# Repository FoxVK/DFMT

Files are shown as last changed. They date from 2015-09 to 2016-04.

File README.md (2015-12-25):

# DFMT
USB Dual FM tuner radio based on PIC 32MX250F128B (or 32MX220F032B) and two LW/SW/FM receivers with I2S output SI4735-D60.

First version of device will alows you to receive sound from first tuner while second tuner can by used for seeking other stations, reciving RDS, obtaining signal metrics, etc...  Unlike SW and FW, hardware was desinged to be as usiversal as possible, so on pcb is interconnection of both audio outputs with MCU, simplified ISP connector and there are soldering pads for both FM and SW/MW/LW inputs.

#Goal
 Be able to receive FM radio with RDS informations.
 
#State of art:
##Firmware:
* Inicialization of tuners is done.
* USB core is done and working.
* USB sunspend is not implemented. Lower power consupmtion to USB spec. limit is not possible but is planned to make it low as possible.
* USB testmode is not implemented and porbably never be because is useful only for certificaion purposes.
* USB-I2C tunnel is done and tested.
* USB audio is done and tesed. (only a subset of audio 1.0 specification)
* USB VID and PID: Random ones are currently used but there seems to be no porblem to get one from Microchip.
* I2C is done and tested.
* I2S is working but there is a problem with discarding buffers due to USB and I2S clock inaccuracy.

##Software:

### Library libdfmt:
* low level interface: Done and tested exept ping.
* Middle level interface is done and tested.
* High level interface is under construction. Only tune cmd is available right now

### Gui:
* Has a bit slow responses because of wrong design
* Tunig and seek works.
* Seek other stations by second tuner. Works but cold be better.
* RDS. Not implemented yet.

## Hardware:
* Schematic was sucessfully tested on breadborad.
* First PCB is finally assembled and successfuly tested.
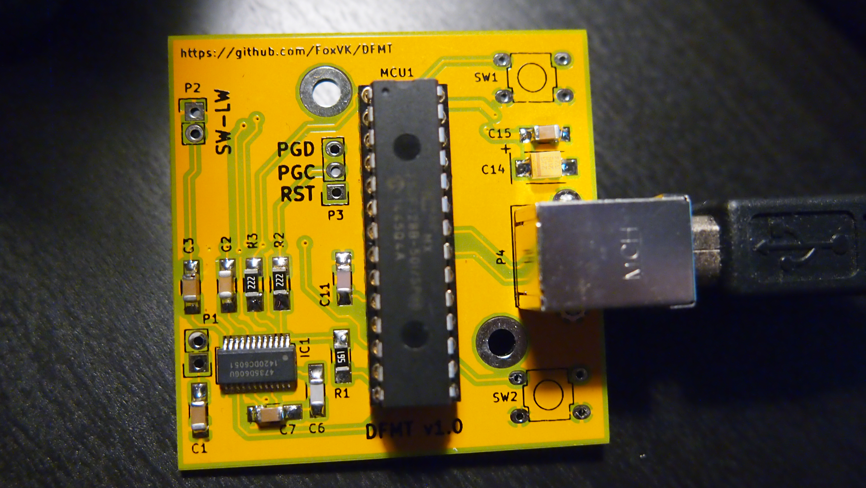
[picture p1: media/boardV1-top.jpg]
PCB

* Issues:
  * Span of holes for buttons is 1mm bigger, but with little bit effort buttons fits.
  * Silkscreen of LE33 and PIC have no orientation mark.
  * Swapped labels PGD and RST.
* Acrylic case could be nice.

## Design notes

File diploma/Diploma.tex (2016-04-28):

% Nejprve uvedeme tridu dokumentu s volbami
\documentclass[czech,master,public,dept460,male,cpdeclaration]{diploma}	% jednostranny dokument

\usepackage[utf8]{inputenc}
\inputencoding{utf8}
\usepackage[czech]{babel}

\usepackage{subfig}		% makra pro "podobrazky" a "podtabulky"
\usepackage{tikz}		% makra pro kresleni

\usepackage{makecell}

\usepackage{pdflscape}

\usepackage{placeins}

\newcommand{\iic}{I\textsuperscript{2}C }
\newcommand{\iis}{I\textsuperscript{2}S }
\newcommand{\eeprom}{E\textsuperscript{2}PROM}

\newcommand{\VID}{0x04D8}
\newcommand{\PID}{0xF32C}

%\widowpenalty10000
%\clubpenalty10000

% Zadame pozadovane vstupy pro generovani titulnich stran.
\ThesisAuthor{Bc. Pavel Kovář}

% U bakalarske praxe neni nutne nazev zadavat
\CzechThesisTitle{Modul USB FM rádia}

% U bakalarske praxe neni nutne anglicky nazev zadavat
\EnglishThesisTitle{USB FM Radio Modul}

\SubmissionDate{29. dubna 2016}

%\PrintPublicationAgreement{true}

\Thanks{Rád bych na tomto místě poděkoval mému vedoucímu panu Ing. Davidu Seidlovi, Ph.D. za cenné rady a trpělivost.}

\CzechAbstract{Tato práce popisuje návrh USB FM přijímače se dvěma tunery. Jeden tuner slouží pro přehrávání zvuku a~druhý pro vyhledávání dalších stanic. Přijímač je v~systému reprezentován jako USB zvuková karta.\\ 
Příjem je realizován dvojicí integrovaných obvodů Si4735-DU. Tyto jsou přes \iis a \iic  spojeny s~MCU PIC32MX250F128B, který přes USB zajišťuje komunikaci s počítačem. V rámci firmware MCU je, po neúspěchu s Microchip harmony frameworkem, napsán vlastní USB stack.\\
Knihovna je napsána v jazyku~C s~využitím knihovny libusb. Poskytuje funkce pro tři úrovně přístupu k~tunerům.\\
Demonstrační aplikace je ve formě grafického uživatelského rozhraní, napsaná  v~C++ s využitím QT frameworku.\\
Vše je funkční pod OS Linux i~Windows.}

\CzechKeywords{FM rádio, USB, RDS, QT, libusb, PIC}

\EnglishAbstract{This work describes design of USB FM radio receiver with two tuners. One tuner is for radio playback, second one seeks new stations. In computer, device acts as sound card.\\
Receiving is done by couple of Si4735-DU integrated circuits, which are connected to MCU via \iic and \iis. MCU forwards data over USB to computer and back. Use of Microchip harmony framework was not successful so in firmware is USB stack written from scratch.\\
Library is written in C with use of libusb library. There are three levels of functions to access tuners.\\
Demo application has graphical user interface and is written in C++ in QT framework.\\
All works under Linux and Windows.}

\EnglishKeywords{FM radio receiver, USB, RDS, QT, libusb, PIC}

% Pridame pouzivane zkratky (pokud nejake pouzivame).
\AddAcronym{AM}{Amlitudová Modulace (Rozhlasové vysílání v pásmu dlouhých vln)}
\AddAcronym{CD}{Compact disc}
\AddAcronym{DAB}{Digital Audio Broadcasting (Digitální pozemní rozhlasové vysílání)}
\AddAcronym{DIP}{Dual Inline Package}
\AddAcronym{FM}{Rozhlasové vysílání v pásmu velmi krátkých vln}
\AddAcronym{HTML}{Hypertext Markup Language}
\AddAcronym{\iic}{Inter-Integrated Circuit}
\AddAcronym{\iis}{Integrated Interchip Sound}
\AddAcronym{LW}{Long Waves (Rozhlasové vysílání v pásmu dlouhých vln)}
\AddAcronym{MCU}{Microcontroller unit}
\AddAcronym{OS}{Operační systém}
\AddAcronym{PCM}{Pulse-code modulation}
\AddAcronym{RDS}{Radio Data System}
\AddAcronym{SPI}{Serial Peripheral Interface}
\AddAcronym{SSOP}{Shrink Small-Outline Package}
\AddAcronym{SW}{Short Waves (Rozhlasové vysílání v pásmu krátkých vln)}
\AddAcronym{USB}{Universal Serial Bus}
\AddAcronym{UTF-16}{Způsob kódování znaků ISO 10646/Unicode}
\AddAcronym{QFN}{Quad Flat No-leads package}

% Zadame cestu a jmeno souboru ci nekolika souboru s digitalizovanou podobou zadani prace
% Pri sazbe se pak hledaji soubory Figures/Zadani1.jpg, Figures/Zadani2.jpg atd.
% Do diplomove prace se postupne vlozi vsechny existujici soubory Figures/ZadaniXXX.jpg
% Pokud toto makro zapoznamkujeme sazi se stranka s upozornenim
\ThesisAssignmentImagePath{figures/zadani}

% Zadame soubor s digitalizovanou podobou prohlaseni
% Pokud toto makro zapoznamkujeme sazi se cisty text prohlaseni
\AuthorDeclarationImageFile{figures/prohlaseni.jpg}

\CooperatingPersonsDeclarationImageFile{figures/souhlas.jpg}

% Zacatek dokumentu
\begin{document}

% Nechame vysazet titulni strany.
\MakeTitlePages

\input{chapters/uvod.tex}

\input{chapters/vyber.tex}
\input{chapters/tuner.tex}
\input{chapters/usb.tex}
\input{chapters/knihovna.tex}

\input{chapters/zaver.tex}

\begin{thebibliography}{99}

\bibitem{usb-complete} AXELSON, Jan. 
\textit{USB complete: the developer's guide.} 4th ed. Madison, WI: Lakeview Research, 2009, xxiii, 504 p. ISBN 1-931448-08-6.

%usb reference
\bibitem{usb-spec} Compaq, Hewlett-Packard, Intel, Lucent, Microsoft, NEC, Philips. 
\textit{Universal Serial Bus Specification: Revision 2.0} [online] 2000-04-27 [2015-12-26]
\url{http://www.usb.org/developers/docs/usb20_docs/usb_20_0702115.zip}

%usb audio 1.0
\bibitem{usb-audio} Gal Ashour, Billy Brackenridge, Oren Tirosh, Altec Lansing, Craig Todd, Remy Zimmermann, Geert Knapen. 
\textit{Universal Serial Bus Device Class Definition for Audio Devices: Release 1.0} [online] 1998-03-18 [2015-12-26]
\url{http://www.usb.org/developers/docs/devclass_docs/audio10.pdf}

%usb audio formats 
\bibitem{usb-audio-formats} Gal Ashour, Billy Brackenridge, Oren Tirosh, Altec Lansing, Craig Todd, Remy Zimmermann, Geert Knapen. 
\textit{Universal Serial Bus Device Class Definition for Audio Data Formats} [online] 1998-03-18 [2016-02-20]
\url{http://www.usb.org/developers/docs/devclass_docs/frmts10.pdf}

%usb lang codes
\bibitem{usb-lang}  USB Implementers’ Forum. 
\textit{Universal Serial Bus Language Identifiers (LANGIDs): Version 1.0} [online] 2000-03-26 [2016-02-09]
\url{http://www.usb.org/developers/docs/USB_LANGIDs.pdf}

\bibitem{tuner-datasheet} Silicon Laboratories,
\textit{Si4730/Si4731/Si4734/Si4735-D60 Broadcast AM/FM/SW/LW Radio Receiver: Rev. 1.2 8/13} [online] 2013-08-08 [2015-12-26] \url{https://www.silabs.com/Support\%20Documents/TechnicalDocs/Si4730-31-34-35-D60.pdf}

\bibitem{tuner-programing} Silicon Laboratories,
\textit{AN332: Si47xx Programming Guide: Rev. 1.0 9/14 } [online] 2014-09-10 [2015-12-26] \url{http://www.silabs.com/Support\%20Documents/TechnicalDocs/AN332.pdf}

%microchip pic
\bibitem{pic} Microchip Technology Inc.
\textit{PIC32MX1XX/2XX Family Data Sheet: Revision H} [online] 2015-07-29 [2015-12-26]
\url{http://ww1.microchip.com/downloads/en/DeviceDoc/60001168H.pdf}

%microchip i2s
%\bibitem{pic-iis} Microchip Technology Inc.
%\textit{PIC32 Family Reference Manual, Sect. 23 Serial Peripheral Interface} [online] 2011-10-11 [2015-12-26]
%\url{http://ww1.microchip.com/downloads/en/DeviceDoc/61106G.pdf}

%microchip i2c
\bibitem{pic-iic} Microchihttp://ww1.microchip.com/downloads/en/DeviceDoc/61116F.pdp Technology Inc.
\textit{PIC32 Family Reference Manual,  Sect 24. Inter-Integrated Circui} [online] 2013-03 [2015-12-26]
\url{http://ww1.microchip.com/downloads/en/DeviceDoc/61116F.pdf}

%microchip dma
%\bibitem{pic-dma} Microchip Technology Inc.
%\textit{PIC32 Family Reference Manual, Sect. 31 DMA Controller} [online] 2013-11-15 [2015-12-26]
%\url{http://ww1.microchip.com/downloads/en/DeviceDoc/60001117H.pdf}

%microchip usb
\bibitem{pic-usb} Microchip Technology Inc.
\textit{PIC32 Family Reference Manual, Sect. 27 USB On-The-Go} [online] 2011-04-13 [2015-12-26]
\url{http://ww1.microchip.com/downloads/en/DeviceDoc/61126F.pdf}

%microchip errata
\bibitem{pic-errata} Microchip Technology Inc.
\textit{PIC32MX1XX/2XX 28/36/44-pin Family Silicon Errata and Data Sheet Clarification} [online] 2015-07-29 [2015-12-26]
\url{http://ww1.microchip.com/downloads/en/DeviceDoc/80000531G.pdf}

%microchip harmony reference
\bibitem{harmony} Microchip Technology Inc.
\textit{MPLAB Harmony USB Libraries Help} [online] 2012-11-15 [2015-12-26]
\url{http://ww1.microchip.com/downloads/en/DeviceDoc/MPLAB\%20Harmony\%20USB\%20Libraries\%20\%28v1.06.02\%29.pdf}

\bibitem{tas}
\textit{TAS1020B USB Streaming Controller} [online] 2011-05 [2015-12-29]
\url{http://www.ti.com/lit/ds/symlink/tas1020b.pdf} 

\bibitem{le} STMicroelectronics
\textit{Very low-dropout voltage regulator with inhibit function} [online] 03-2014 [2016-01-09]
\url{http://www.st.com/st-web-ui/static/active/en/resource/technical/document/datasheet/CD00000545.pdf}

\bibitem{usb-vid} USB.org
\textit{Getting a Vendor ID} [online] [2016-01-16]
\url{http://www.usb.org/developers/vendor/}

\bibitem{iis} Philips Semiconductors
\textit{\iis bus specification} [online] 1996-06-05 [2016-02-27]
\url{http://www.st.com/st-web-ui/static/active/en/resource/technical/document/datasheet/CD00000545.pdf}

\bibitem{rds} EN 50067
\textit{Specification of the radio data system (RDS) for VHF/FM sound broadcasting in the frequency range from 87,5 to 108,0 MHz} CELNEC 04-1998 [2016-04-01]

\bibitem{libwdi} Pete Batard
\textit{libwdi: A Windows Driver Installation library for USB devices} [online] 2016-01-22 [2016-04-25]
\url{https://github.com/pbatard/libwdi#libwdi-a-windows-driver-installation-library-for-usb-devices}

\bibitem{zadig} Pete Batard
\textit{Zadig} [online] 2014-11-21 [2016-04-25]
\url{https://github.com/pbatard/libwdi/wiki/Zadig}

\bibitem{wcid} Pete Batard
\textit{WCID Devices} [online] 2014-11-21 [2016-04-25]
\url{https://github.com/pbatard/libwdi/wiki/WCID-Devices}

\end{thebibliography}

\appendix

\section{Adresářová struktura  přiloženého CD}
\label{sec:ap-cd}

\begin{itemize}
\item \textbf{diploma.pdf}: Tento text.

\item \textbf{firmware}: Projekt pro vývojové prostředí MplabX s firmwarem pro MCU.
	\begin{itemize}
	\item \textbf{dist/default/production/}: Přeložený souboru s firmwarem pro MCU.
	\end{itemize}

\item \textbf{software}: Mutiprojekt s knihovnou a demonstrační aplikací pro vývojové prostředí QT~Creator.
	\begin{itemize}
	\item \textbf{bin}:
		\begin{itemize}
		\item \textbf{win32}: 32-bitová verze knihovny a demonstrační aplikace pro OS Windows.
		\item \textbf{linuxX86\_64}: 64-bitová verze knihovny a demonstrační aplikace pro OS Linux.
		\end{itemize}
	\item \textbf{driver}: Instalátor ovladače pro OS Windows.
	\item \textbf{dfmtgui}: Projekt s demonstrační aplikací.
	\item \textbf{libdfmt}: Projekt s knihovnou.
	\begin{itemize}
		\item \textbf{doc}: Vygenerovaná dokumentace knihovny.
		\end{itemize}
	\end{itemize}
	
\item \textbf{hardware}:
	\begin{itemize}
	\item \textbf{exports}: Schéma ve formátu pdf a soubory pro výrobu desky plošných spojů.
	\item \textbf{kicad}: Projekt se schématem a deskou plošných spojů pro aplikaci KiCad.
	\end{itemize}

\end{itemize}

%\begin{landscape}

\section{Schéma zapojení modulu}
\label{sec:ap-schema}
%Na štorc
%\InsertFigure{figures/dfmt.eps}{50mm}{Schéma zapojení modulu.}{fig:schema}

\begin{center}
 
\end{center}
 
\section{Rozpiska součástek}
\label{sec:ap-bom}
\begin{center}
\begin{tabular}{|l|r|r|r|l|}

\hline
Označení	& Název &	Počet	&	Pouzdro	&	Parametry\\
\hline
\makecell[l]{C1, C7, C9, C12,\\C15, C16}	&	Kondenzátor	&	6	&	1206	&	100 nF 5 \% X7R  50 V\\
\hline
C2, C4	&	Kondenzátor	&	2	&	1206	& 1 nF 5 \% X7R  50 V\\
\hline
C3, C5	&	Kondenzátor	&	2	&	1207	&	470 nF 5 \% X7R  50 V\\
\hline
C6, C8	&	Kondenzátor	&	2	&	1206	&	22 nF 5 \% X7R  50 V\\
\hline
C10, C11	&	Kondenzátor	&	2	&	1206	&	18 pF 5 \% X7R  50 V\\
\hline
C13, C14	&	Kondenzátor	&	2	&	B	&	2,2 $\mu$F 10 \% Tantal 16V \\
\hline
C17	&	Kondenzátor	&	1	&	B	&	10 $\mu$F 10 \% Tantal 16V \\
\hline
IC1, IC2	&	IO	&	2	&	SSOP24	&	SI4735-D60\\
\hline
IC3	&	IO	&	1	&	SO 8	&	LE33-SMT\\
\hline
L1	&	Tlumivka	&	1	&	1210	&	10 $\mu$H 10 \% 180 mA 1,6 $\Omega$\\
\hline
MCU1	&	IO	&	1	&	DIP28	&	PIC32MX220F032B\\
\hline
MCU1	&	Patice	&	1	&	DIP28	&	\\
\hline
P4	&	Konektor	&	1	&		&	USB B zásuvka  MOLEX 670688000 \\
\hline
R1, R4	&	Rezistor	&	2	&	1206	&	560 $\Omega$ 5 \%\\
\hline
R2, R3, R5, R6	&	Rezistor	&	4	&	1206	&	2,2 k$\Omega$ 5 \%\\
\hline
R7, R8, R9	&	Rezistor	&	3	&	1206	&	4,7 k$\Omega$ 5 \%\\
\hline
SW1, SW2	&	Tlačítko	&	2	&		&	TACT 613 N (neosazeno)\\
\hline
Y1	&	Krystal	&	1	&		&	8 MHz 30 ppm HC49SM 18 pF\\
\hline
-	&	Anténa &	1	&	& Vodič	38 cm AWG24\\
\hline

\end{tabular} 
\end{center}
%\end{landscape}

%\clearpage

%\InsertFigure{figures/Graf}{0.7\textwidth}{Nějaký graf}{fig:SampleGraph}

\section{Fotografie osazené desky plošných spojů}
\label{sec:ap-pcb}

\subsection*{Horní strana:}
\begin{center}
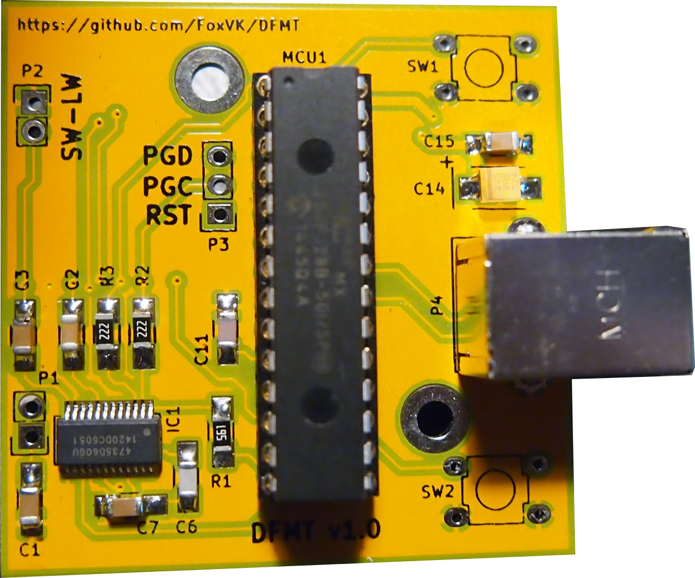
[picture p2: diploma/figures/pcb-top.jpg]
 
\end{center}

\subsection*{Spodní strana:}
\begin{center} 
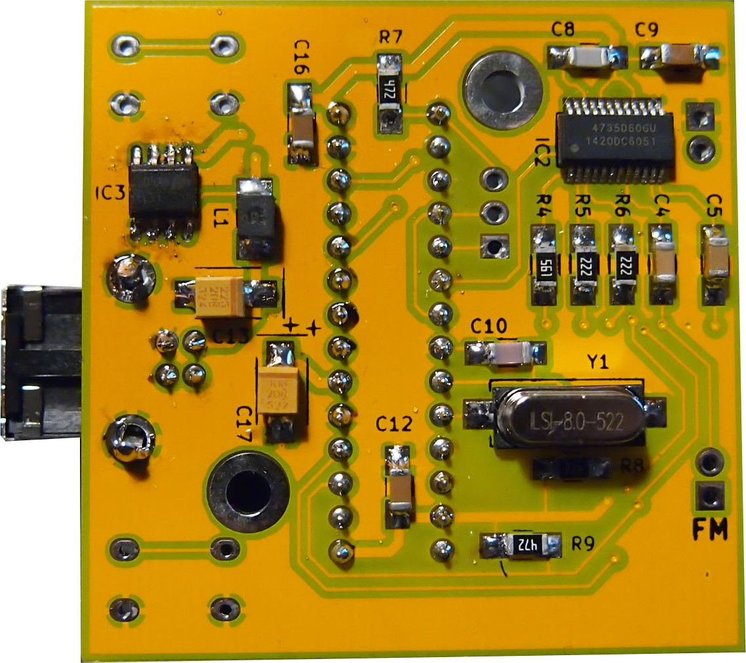
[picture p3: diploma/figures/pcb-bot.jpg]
 
\end{center}

\end{document}

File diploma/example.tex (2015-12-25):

\section{Ukázky sazby}
\label{sec:Typo}

\subsection{Ukázka nadpisů}
Toto je nadpis podsekce, generováno makrem \verb|\subsection|.

\subsubsection{subsection}

\paragraph{paragraph}

\subparagraph{subparagraph}
Ale tak hluboko se asi stejně nikdo nedostane.

\subsection{Sazba definic, vět atd.}
Určitě se bude hodit prostředí pro sazbu definice jako je definice binárního vyhledávacího
stromu, viz definice \ref{def:BinVyhlStrom}.

\begin{remark}
Následující definice a věty nedávají dohromady příliš smysl. Jsou tu jen pro ukázku.
\end{remark}

\begin{definition}
\label{def:BinVyhlStrom}
Binární strom je struktura definovaná nad konečnou množinou uzlů, která:
\begin{itemize}
\item neobsahuje žádný uzel,
\item je složena ze tří disjunktních množin uzlů:
      kořene, binárního stromu zvaného levý podstrom a~binárního stromu tzv.\ pravého podstromu.
\end{itemize}
\end{definition}

Pak by se taky mohla hodit nějaká věta a k ní důkaz.

\begin{theorem}
\label{VetaNeuspechSepar}
Průměrná časová složitost neúspěšného vyhledání  v~hashovací tabulce se  separátním zřetězením je $\Theta(1+\alpha)$, za předpokladu jednoduchého uniformního hashování.
\end{theorem}
\begin{proof}
Za předpokladu jednoduchého uniformního hashování se každý  klíč
$k$ hashuje se stejnou pravděpodobností do libovolného z~$m$ slotů
tabulky. Průměrný čas neúspěšného hledání klíče $k$ je proto
průměrný čas prohledání jednoho z~$m$ seznamů. Průměrná délka
každého takového seznamu je rovna faktoru naplnění $\alpha=n/m$.
Tudíž lze očekávat, že budeme nuceni prozkoumat $\alpha$ prvků.
Z~toho plyne, že celkový čas pro neúspěšné hledání (plus navíc
konstantní čas pro výpočet $h(k)$) je $\Theta(1+\alpha)$.
\end{proof}

\begin{example}
\label{priklad}
Mějme napsat funkci, která spočítá uzly ve stromu. Předpokládejme,
že binární strom je definován způsobem uvedeným v~definici
\ref{def:BinVyhlStrom} na straně \pageref{def:BinVyhlStrom}. Naše úloha se výrazně zjednoduší
uvědomíme-li si její rekurzivní charakter a~předpokládáme, že aktuální uzel je $R$.
\begin{itemize}
\item Je-li $R$ prázdný strom (tj.\ $R=NULL$), pak počet jeho uzlů je pochopitelně nula. Tím máme problém vyřešen.

\item V~opačném případě víme, že ve stromu  určitě jeden uzel existuje ($R$) a~počty uzlů
v~levém a~pravém podstromu se dají určit obdobným způsobem
rekurzivně. To znamená, že počet uzlů ve stromu s~kořenem $R$ je
$1 + \mathrm{pocet\_uzlu}(A) + \mathrm{pocet\_uzlu}(B)$
\end{itemize}

Počty uzlů pro jednotlivé podstromy se předávají jako výsledky
volání funkcí prostřednictvím zásobníku programu, nejsou tudíž
potřeba žádné pomocné proměnné.
\end{example}

\begin{remark}
Program z příkladu \ref{priklad} pochopitelně chybí,
ale můžete se podívat třeba na program uvedený ve výpisu \ref{src:Java}.
\end{remark}

\subsection{Výpisy programů}
Tato diplomová práce má nastaven výchozí jazyk Java, jak je vidět z výpisu~\ref{src:Java}. Výpis kódu \ref{src:Java} zároveň demonstruje možnost přímého vložení zdrojového kódu programu do textu práce. Druhou možností je načtení zdrojového kódu programu z externího souboru, viz výpis \ref{src:JavaExternal}. Pokud potřebujeme změnit programovací jazyk pro konkrétní výpis kódu, můžeme jeho to provést přímo v záhlaví prostředí \verb|lstlisting|. Výpis \ref{src:Pascal} je v jazyku Pascal. Všimněte si zvýraznění klíčových slov. 

\begin{remark}
Pro správnou sazbu je třeba pro odsazování používat tabulátory, nikoliv mezery.
\end{remark}

\begin{lstlisting}[label=src:Java,caption=Program v jazyce Java]
public class MyClass
{
	public int MyMethod(int a, int b)
	{
		while (a != b)
		{
			if (a < b)
				b -= a;
			else
				a -= b;
		}
	}
}
\end{lstlisting}

%\lstinputlisting[label=src:JavaExternal,caption={Program v jazyce Java, načtený z externího souboru}]{MyClass.java}

\begin{lstlisting}[language=Pascal,label=src:Pascal,caption=Program v Pascalu]
procedure X(i : integer; var x : real);
begin
	x := i + 3;
end;
\end{lstlisting}

\subsection{Obrázky a tabulky}
A ještě si můžeme zkusit vysázet obrázek. Obrázek \ref{fig:SampleFigAbs} má určenu absolutní velikost,
zatímco obrázek \ref{fig:SampleFigRel} je určen relativně vůči šířce textu.

\InsertFigure{figures/Obr1}{40mm}{Pokusný obrázek -- absolutní velikost}{fig:SampleFigAbs}

\InsertFigure{figures/Obr1}{0.7\textwidth}{Pokusný obrázek -- relativní velikost}{fig:SampleFigRel}

\InsertSidewaysFigure{figures/Obr1}{0.6\textheight}{Pokusný obrázek -- otočený naležato}{fig:SampleFigSideway}

A ještě zkusíme vysázet několik tabulek, ale jen kvůli seznamu tabulek v úvodu. Tabulka \ref{tab:ExpTable} představuje jednoduchou tabulku, která se svou šířkou pohodlně vejde do šířky textu. Velké tabulky, stejně jako obrázky, můžeme vysázet naležato. Ukázkou velké, komplikované tabulky\footnote{Pokud, ale píšete práci česky, měly by být tabulky také česky -- mě se jen nechtěla předělávat do češtiny.} je tabulka \ref{tab:ExpFilesDetailStats}.
 
\begin{table}
  \centering
  \begin{tabular}{|c|c|c|}
    \hline
    q & $\delta(q, 0)$ & $\delta(q, 1)$ \\
    \hline
    $q_0$ & $q_1$ & $q_0$ \\
    \hline
    $q_1$ & $q_1$ & $q_2$ \\
    \hline
    $q_2$ & $q_1$ & $q_0$ \\
    \hline
  \end{tabular}
  \caption{Pokusná tabulka}
  \label{tab:ExpTable}
\end{table}

\begin{sidewaystable}
\centering
\begin{tabular}{|l|rr|rr|rr|rr|}
\hline
File &
\multicolumn{2}{c|}{bible.txt} &
\multicolumn{2}{c|}{world.txt} &
\multicolumn{2}{c|}{law.txt} &
\multicolumn{2}{c|}{latimes.txt} \\
\hline
Language &
\multicolumn{2}{c|}{English} &
\multicolumn{2}{c|}{English} &
\multicolumn{2}{c|}{Czech} &
\multicolumn{2}{c|}{English} \\
Format &
\multicolumn{2}{c|}{Plain text} &
\multicolumn{2}{c|}{Plain text} &
\multicolumn{2}{c|}{Plain text} &
\multicolumn{2}{c|}{SGML} \\
\hline
Size of file [bytes] & 4047392 &  & 2473400 &  & 64573143 &  & 498360166 & \\
\hline
{\small{}Number of tokens} & 1532262 & 100\% & 684767 & 100\% & 19432898 & 100\% & 161254928 & 100\%\\
{\small{}Number of words} & 766131 & 50\% & 342383 & 50\% & 9716449 & 50\% & 70766067 & 43.885\%\\
{\small{}Number of nonwords} & 766131 & 50\% & 342384 & 50\% & 9716449 & 50\% & 80619289 & 49.995\%\\
{\small{}Number of controls} &  &  &  &  &  &  & 9869572 & 6.12\%\\
\hline
{\small{}Number of unique tokens} & 13791 & 100\% & 23564 & 100\% & 250570 & 100\% & 529482 & 100\%\\
{\small{}Number of unique words} & 13744 & 99.659\% & 23082 & 97.955\% & 246266 & 98.282\% & 524280 & 99.018\%\\
{\small{}Number of unique nonwords} & 47 & 0.341\% & 482 & 2.045\% & 4304 & 1.718\% & 3079 & 0.582\%\\
{\small{}Number of unique controls} &  &  &  &  &  &  & 2123 & 0.401\%\\
\hline
{\small{}Word average frequency} & 55.743 &  & 14.833 &  & 39.455 &  & 134.978 & \\
{\small{}Nonword average frequency} & 16300.66 &  & 710.34 &  & 2257.539 &  & 26183.595 & \\
{\small{}Control average frequency} &  &  &  &  &  &  & 4648.88 & \\
\hline
{\small{}Minimal length of word} & 1 &  & 1 &  & 1 &  & 1 & \\
{\small{}Maximal length of word} & 18 &  & 27 &  & 41 &  & 58 & \\
{\small{}Minimal length of nonword} & 1 &  & 1 &  & 1 &  & 1 & \\
{\small{}Maximal length of nonword} & 4 &  & 56 &  & 700 &  & 253 & \\
{\small{}Minimal length of control} &  &  &  &  &  &  & 3 & \\
{\small{}Maximal length of control} &  &  &  &  &  &  & 132 & \\
\hline
\end{tabular}
\caption{Experimental Files --- Detailed Statistics}
\label{tab:ExpFilesDetailStats}
\end{sidewaystable}

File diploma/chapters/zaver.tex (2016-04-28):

\section{Závěr}
\label{sec:Conclusion}

\InsertFigure{figures/breadborad-landscape.jpg}{123mm}{Modul v kontaktním poli.}{fig:breadborad}

Cílem této práce byl návrh modulu USB FM přijímače, který je v operačním systému reprezentován jako zvuková karta. Přijímač má obsahovat dva tunery, kdy jeden má být používán pro~přehrávání a druhý pro vyhledávání dalších stanic. 

Prvníma dvěma úkoly byl výběr vhodných součástek a ověření funkce zařízení na kontaktním poli. Toto je rozebráno v kapitole \ref{sec:Vyber}. Byly vybrány tunery ve formě integrovaných obvodů SI4735-D60, které budou na sběrnici USB připojeny prostřednictvím mikrokontroléru PIC32MX250F128B. Výslednou konstrukci nejlépe ilustruje obrázek \ref{fig:tuner-block} na straně \pageref{fig:tuner-block}. Do mikrokontroléru byl napsán firmware s vlastním zjednodušeným ovladačem USB. Nad tímto ovladačem běží USB - \iic tunel, pomocí kterého jsou ovládány tunery a rozhraní, které přeposílá digitální zvuk z tunerů do USB. Funkčnost vzniklého zařízení jsem úspěšně ověřil na kontaktním poli (viz.~obrázek \ref{fig:breadborad}). Nad rámec zadání jsme navíc navrhl  desku plošných spojů, na které jsem zařízení úspěšně oživil (fotografie v příloze~\ref{sec:ap-pcb}). Zařízení má v této podobně mnohem kvalitnější příjem. Schéma zapojení je v příloze \ref{sec:ap-schema}. Zároveň je v elektronické verzi spolu s podklady pro výrobu DPS umístěn na~přiloženém CD.

Třetím úkolem bylo napsat knihovnu pro práci s tunerem pod OS Linux a Windows. Knihovna byla napsána v jazyce C s využitím multiplatformní knihovny libusb. Knihovna je rozdělena do~třech vrstev a umožňuje tak snadné rozšíření funkcionality. Knihovna v současné podobně umožňuje přeladění vybraného tuneru na danou frekvenci, vyhledávání stanic a vyčtení parametrů naladěné stanice. Knihovna také byla doplněna o možnost příjmu RDS dat. Ovládání tunerů knihovnou je popsáno v kapitole \ref{sec:tuner}. Samotná knihovna je popsána v kapitole \ref{sec:knihovna}, její rozhraní je podrobně popsáno v dokumentaci vygenerované nástrojem Doxygen, která je umístěna na~přiloženém CD.

Čtvrtým a poslední úkolem bylo napsat uživatelský program, který bude demonstrovat využití knihovny. Napsal jsem aplikaci s grafickým uživatelským rozhraním s využitím multiplatformního frameworku QT5. Tato aplikace umožňuje ladění frekvencí, vyhledávání stanic, zobrazuje parametry signálu naladěné frekvence a její RDS radio text. Zároveň, jak~je~požadováno v~úvodu zadání, průběžně druhým tunerem vyhledává dostupné stanice a zobrazuje je~v~tabulce. Rozhraní nejlépe ilustruje obrázek \ref{fig:gui} na straně \pageref{fig:gui}.

%\subsection{Omezení}

%TODO:
%\begin{itemize}

%\item Nemožnost dostat se v suspendu do 0,5 mA
%\item Test mód neimplementován. Nutný pouze pro získání USB loga.

%suspend a test mod
%\end{itemize}
\FloatBarrier
\subsection{Možnosti dalšího rozšíření}
Hardware a částečně i firmware MCU je připraven pro přenos zvuku i z druhého tuneru. Vhodným doplnění deskriptoru USB konfigurace by bylo možno zařízení přepínat do režimu dvou zvukových karet. Poté by bylo možné nahrávat jinou stanici při současném přehrávání jiné a~nebo využít zařízení pro~streaming několika rozhlasových stanic.  

Na desce plošných spojů jsou připraveny pozice pro dvě tlačítka, která zatím nejsou osazena. Drobnou úpravou firmware by bylo možné využít je k vyhledávání stanic bez potřeby jakéhokoliv dalšího software, popřípadě stisky tlačítek posílat přes USB do aplikace a tam je dále libovolně vyhodnocovat.

Tunery umožňují příjem rozhlasu i na středních a dlouhých vlnách. Toto by vyžadovalo jednak úpravu knihovny, která tunery přepne do režimu pro příjem těchto pásem a také by bylo třeba hardware doplnit o vhodnou anténu spolu s transformátorem viz. katalogový list \cite{tuner-datasheet}.

Uživatelskou aplikaci by bylo vhodné doplnit minimálně o možnost ovládat přehrávání zvuku a popřípadě jeho záznam. Dále je možné doplnit tabulku dostupných frekvencí o informace z~RDS. Taktéž by bylo možné na základě těchto informací automatiky přelaďovat na frekvenci s kvalitnějším příjmem stejné stanice.

\bigskip
\begin{flushright}
Bc. Pavel Kovář
\end{flushright}

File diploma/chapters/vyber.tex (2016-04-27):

\section{Výběr součástek}
\label{sec:Vyber}
Vzhledem k tomu, že není možné se cenou zařízení přiblížit zavedeným výrobcům elektroniky, rozhodl jsme se výběr součástek a~konstrukci modulu přizpůsobit tak, aby bylo možné modul vyrobit v domácích podmínkách.

%mužeš přidat zmínku o snaze mít možnost rozšiřování funkcionality po strance FW a SW
%možná by stáo za to popsat i2s
 
\subsection{Způsob příjmu rozhlasového vyslání}
Jednou možností je řešení přijímačem složeným z diskrétních součástek a nebo pomocí analogových IO. Ovšem toto je příliš komplikované.

Na trhu je řada integrovaných obvodů, které zajišťují samotný příjem vysílání včetně vyhledávání static, měření kvality signálu a přijmu RDS a to s minimem potřebných externích součástek. Tyto IO se typicky ovládají pomocí \iic nebo SPI a zvuk poskytují digitálně přes rozhraní \iis popřípadě analogově. Bohužel drtivá většina těchto IO je dostupná pouze v pouzdru QFN, které se velmi obtížně pájí a je možné je sehnat pouze v minimálním množství 1000 kusů. Výjimkou je SI4735-D60 od výrobce SILICON LABS, který je dostupný v pouzdru SSOP24 a~je možné jej u nás zakoupit i po jednotlivých kusech. IO neumožňuje přijímat DAB, ale umí následující:
\begin{itemize}
\item{Pásma: FM, SW, MW, LW.}
\item{Vzorkovací frekvence až do 48kHz.}
\item{Rozlišení vzorku kanálu až do 24bitů.}
\item{Stereofonní příjem.}
\item{Příjem RDS.}
\end{itemize}
%popis vlastností jako že jsou na 3.3v a taky vypíchnoout že frekvence se dá odvozovat přímo z i2s

\subsection{Volba rozhraní pro spojení modulu a počítače}
Po tomto rozhraní se budou přenášet dva druhy informací a to samotný zvuk a ovládání tunerů.

V současné době je prakticky jediným schůdným řešením použití rozhraní USB díky celé řadě výhod, které nabízí. Zejména jeho širokým rozšířením na téměř všech počítačích, od osobních přes servery až po jednodeskové či průmyslové počítače. Stejně tak je k~dispozici velké množství součástek se zabudovanou podporou tohoto rozhraní. USB dále poskytuje možnost napájení připojených zařízení až do příkonu 2,5 W. Má zabudovanou podporu pro různé druhy přenosů včetně isochronních (garantovaný periodický přenos předem dohodnutého množství dat). Specifikace USB zavádí standardní třídy funkcí v~zařízení. V době psaní tohoto textu sice neexistuje třída pro ovládání tuneru, ale existuje třída popisující zvuková zařízení. Díky tomuto není potřeba vyvíjet vlastní ovladač zvukové karty na straně počítače.
%mužeš to vycpat textem o PCI - PCI-e
\subsubsection{Verze USB specifikací}
V současné době je možné se setkat s USB verze 1.0, 1.1, 2.0 a 3.0. Dobrou zprávou je zpětná kompatibilita všech verzí. tj. zařízení podle specifikace 1.0 by mělo fungovat s jakýmkoliv hostem. Rychlost full speed definuje už první specifikace, její maximální propustnost 12 Mbit je pro věrný přenos dvoukanálového zvuku více než dostatečná. Novější verze nepřinášejí žádnou vlastnost, která by byla pro tento projekt přínosná.

Odlišná situace je v případě specifikací třídy USB audio. Existují vzájemně nekompatibilní verze 1.0 a 2.0. Ani zde mladší verze nepřináší žádný benefit, který bych mohl využít. Navíc doposud nemá nativní podporu ani ve Windows 10. Z tohoto důvodu není použití USB audio 2.0 příliš vhodné.

\subsection{Napojení tuneru na USB}
Požadavky:

\begin{itemize}
\item{Schopnost přenášet dvoukanálový zvuk bez znatelného zkreslení. Zvolil jsem PCM formát o vzorkovací frekvenci 48 kHz a rozlišení 16 bitů na jeden kanál. Pro srovnání audio CD používá 44,1 kHz / 16bitů.}
\item{Alespoň jedno rozhraní \iis schopné přijímat zvuk a fungující v režimu master.}
\item{Podporu pro USB audio. To implikuje nutnost podpory full speed USB a nebo rychlejší. Low speed nepodporuje isochronní přenosy, které jsou nezbytné pro přenos zvuku.}
\item{Rozhraní \iic master pro ovládání tunerů.}
\item{Kompatibilita s 3,3 V logikou tunerů.}
\end{itemize}

\subsubsection{TAS1020b}	
\InsertFigure{figures/tas-block.png}{\textwidth}{Blokové schéma TAS1020b. (Převzato z \cite{tas})}{fig:tas-block}

Jak je patrné z obrázku \ref{fig:tas-block}, jedná se o USB \iis zvukovou kartu a MCU v jednom. Na~rozdíl od~většiny MCU nemá interní paměť programu. Program se načítá při spuštění buď z E\textsuperscript{2}PROM  paměti připojené přes \iic a nebo přes USB ze zařízení, ke kterému je obvod připojen.

Obvod podle specifikace \cite{tas} podporuje všechno potřebné. Full speed USB 1.1 včetně USB audio 1.0, 14 endpointů z toho až dva mohou být isochronní. Dále nabízí až dvě vstupní \iis rozhraní a~jednu \iic sběrnici. Nevýhodou je absence programové paměti, kusová dostupnost obvodu pouze ve formě vzorků a v~mém případě také fakt, že s tímto druhem obvodů nemám žádné zkušenosti.

\subsubsection{PIC16F1454}
PIC16F1454 je osmi bitový MCU od firmy Microchip s podporou full speed USB 2.0. Obvod obsahuje továrně kalibrovaný oscilátor a umí pracovat při napájecím napětí 2,3-5,5V. Díky tomu obvod nepotřebuje prakticky žádné externí součástky. V podstatě k~němu stačí připojit pouze USB kabel.

Výrobce poskytuje k~tomuto MCU knihovnu Microchip Library for aplications, která mimo jiné obsahuje implementaci USB audio 1.0. Navíc jedním ze vzorových projektů u~této knihovny je~i~USB mikrofón, který řeší přenos zvuku do počítače.

Bohužel tento MCU nemá podporu \iis a na jeho softwarovou implementaci je příliš pomalý. 

\subsubsection{PIC32MX250F128}
Tento 32 bitový MCU, taktéž od firmy Microchip, je vybaven všemi potřebnými rozhraními. Full speed USB 2.0, 2x nezávislé \iis, 2x \iic. Pracuje v rozmezí napájecích napětí 2,3-3,6V. V MCU jsou k~dispozici čtyři DMA kanály, které je možné řetězit (po ukončení jednoho kanálu se automaticky spustí druhý). Podobně jako u PIC16F1454 je i k~tomuto čipu k~dispozici framework Harmony \cite{harmony} s podporou pro USB Audio 1.0. Vyrábí se v~různých pouzdrech, dokonce i v DIP, které je možné přímo zapojit do nepájivého pole.\\
Pro modul jsem vybral právě tento MCU. Případně je možné něco málo ušetřit a použít PIC32MX220F032. Liší se pouze menšími velikostmi pamětí, konkrétně 32kB programové paměti místo 128kB a 8kB datové paměti namísto 32kB.

\subsection{Výsledná konstrukce}
\label{subsec:konstrukce}
\InsertFigure{figures/tuner-block.eps}{100mm}{Blokové schéma zapojení.}{fig:tuner-block}

Propojení jednotlivých komponent je naznačeno na obrázku \ref{fig:tuner-block}. Jak je patrné, zahrnul jsem i~propojení tuneru B s MCU přes \iis a také vyvedení anténních AM vstupů tunerů (v obrázku čárkovaně). Aktuálně nejsou využity, ale v budoucnu bude možné zařízení rozšířit o podporu příjmu všech pásem, které tunery podporují a nebo přidat režim, kdy se modul bude chovat jako dvě nezávislé zvukové karty.

Celé zařízení je napájeno z USB přes jediný lineární stabilizátor LE33CD, který snižuje napájecí napětí na~3,3V. Dokáže poskytnout až 100mA a~je odolný proti nadproudu a přehřátí \cite{le}. MCU je zapojen podle doporučení v~katalogovém listu \cite{pic} kapitola 2.1. Stejně tak tunery jsou zapojeny podle doporučení v katalogovém listu \cite{tuner-datasheet} kapitola 2.2.

 Tady bych chtěl zmínit vstup RCLK. Tuner potřebuje v době ladění hodinový signál. V~katalogovém listu je několikrát zmíněno, že tento signál je nutné buď přivést přímo na vstup RCLK a~nebo se získá zapojením 32,768 kHz krystalu. Až v programovací příručce \cite{tuner-programing} v popisu parametru REFCLK\_PRESCALE je možnost odvodit hodinový signál od vstupu hodinového signálu \iis DCLK. Této možnosti jsem samozřejmě využil.
 
Kompletní schéma zapojení je v příloze \ref{sec:ap-schema} a také na přiloženém CD.

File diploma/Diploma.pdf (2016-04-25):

## VŠB – Technická univerzita Ostrava

## Fakulta elektrotechniky a informatiky

## Katedra informatiky

# Modul USB FM rádia

# USB FM Radio Modul

2016 | Bc. Pavel Kovář

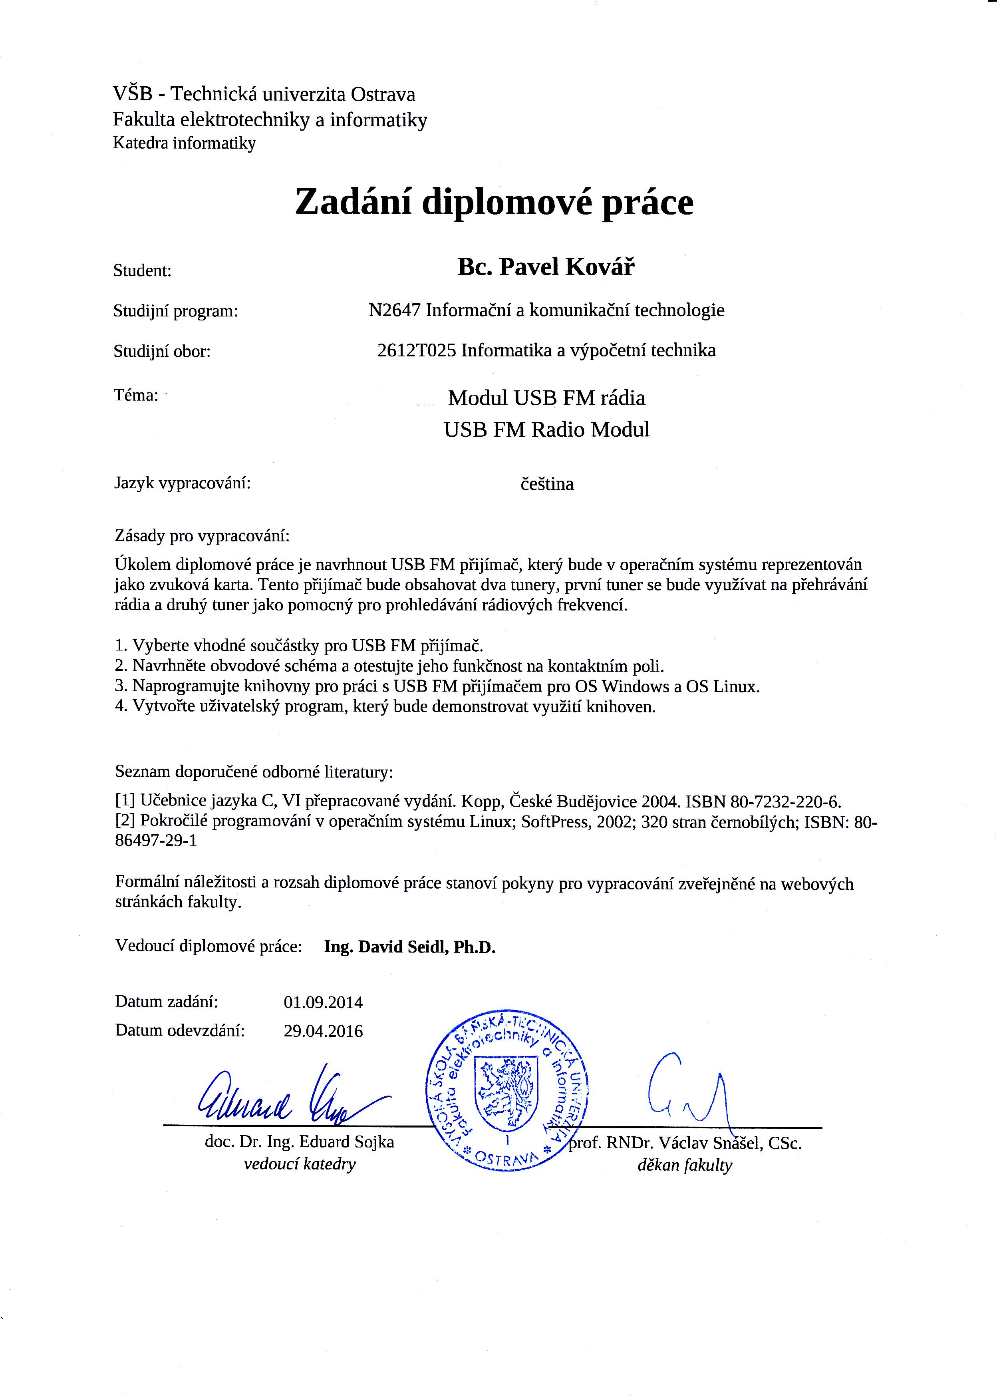
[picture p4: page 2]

Prohlašuji, že jsem tuto diplomovou práci vypracoval samostatně. Uvedl jsem všechny literární prameny a publikace, ze kterých jsem čerpal.

V Ostravě 27. dubna 2016 | |

Souhlasím se zveřejněním této diplomové práce dle požadavků čl. 26, odst. 9 Studijního a zkušebního řádu pro studium v magisterských programech VŠB-TU Ostrava.

V Ostravě 27. dubna 2016 | |

Rád bych na tomto místě poděkoval zejména mému vedoucímu cenné rady a trpělivost.

Abstrakt

Tato práce popisuje návrh USB FM přijímače se dvěma tunery. Jeden tuner slouží pro přehrávání zvuku a druhý pro vyhledávání dalších stanic. přijímač je v systému reprezentován jako USB zvuková karta.
Příjem je realizován dvojicí integrovaných obvodů Si4735-DU. Tyto jsou přes I²S a I²C spojeny

s MCU PIC32MX250F128B, který přes USB zajišťuje komunikaci s počítačem. V rámci firmware MCU je, po neúspěchu s Microchip harmony frameworkem, napsán vlastní USB stack. Knihovna je napsána v jazyku C s využitím knihovny libusb. Poskytuje funkce pro tři úrovně přístupu k tunerům.
Demonstrační aplikace je ve formě grafického uživatelského rozhraní, napsaná v C++ s využitím QT frameworku.
Vše je funkční pod OS Linux i Windows.

Klíčová slova: FM rádio, USB, RDS, QT, libusb, PIC

Abstract

This work describes design of USB FM radio receiver with two tuners. One tuner is for radio playback, second one seeks new stations. In computer, device acts as sound card.
Receiving is done by couple of Si4735-DU integrated circuits, which are connected to MCU via I

2C and I²S . MCU forwards data over USB to computer and back. Use of Microchip harmony

framework was not successful so in firmware is USB stack written from scratch.
Library is written in C with use of libusb library. There are three levels of functions to access tuners.
Demo application has graphical user interface and is written in C++ in QT framework.
All works under Linux and Windows.

Key Words: FM radio receiver, USB, RDS, QT, libusb, PIC

## Obsah

Seznam použitých zkratek a symbolů | 9
Seznam obrázků | 10
Seznam tabulek | 11
1 Úvod | 12
2 Výběr součástek | 13
3 Tuner | 17
4 USB | 26
5 Knihovna a demonstrační aplikace | 48
6 Závěr | 53
Literatura | 54
Přílohy | 55

7

A Schéma zapojení modulu | 56
B Rozpiska součástek | 57

8

## Seznam použitých zkratek a symbolů

AM | – | Amlitudová Modulace (Rozhlasové vysílání v pásmu dlouhých vln)
CD | – | Compact disc
DAB | – | Digital Audio Broadcasting (Digitální pozemní rozhlasové vysílání)
DIP | – | Dual Inline Package
FM | – | Rozhlasové vysílání v pásmu velmi krátkých vln
HTML | – | Hypertext Markup Language
I
2C | – | Inter-Integrated Circuit

I

2S | – | Integrated Interchip Sound
LW | – | Long Waves (Rozhlasové vysílání v pásmu dlouhých vln)
MCU | – | Microcontroller unit
PCM | – | Pulse-code modulation
RDS | – | Radio Data System
SPI | – | Serial Peripheral Interface
SSOP | – | Shrink Small-Outline Package
SW | – | Short Waves (Rozhlasové vysílání v pásmu krátkých vln)
USB | – | Universal Serial Bus
UTF-16 | – | Způsob kódování znaků ISO 10646/Unicode
QFN | – | Quad Flat No-leads package

9

## Seznam obrázků

1 | Blokové schéma TAS1020b. (Převzato z [15]) | | 15
2 | Blokové schéma zapojení | | 16
3 | Časový diagram I²S přenosu. (Převzato z [18]) | | 18
4 | Diagram inicializace tuneru | | 19
5 | Příklad topologie USB sběrnice | | 27
6 | USB koncové body a funkce | | 27
7 | Formát deskriptoru USB bufferu předaného do USB modulu. (Převzato z [12].) . | 41
8 | Formát deskriptoru USB bufferu předaného do aplikace. (Převzato z [12].) . . . . | 41
9 | Zjednodušený diagram stavů USB zařízení | | 44
10 | Instalace ovladače pro Windows | | 51

10

## Seznam tabulek

1 | Popis I²S signálů | | 17
2 | I²C adresy | | 17
3 | Formát příkazu pro tuner | | 18
4 | Formát odpovědi tuneru | | 18
5 | Příkaz spuštění tuneru POWER_UP | | 20
6 | Proměnné použité pro inicializaci tuneru | | 21
7 | Příkaz spuštění tuneru FM_TUNE_FREQ | | 21
8 | Příkaz zjištění stavu ladění FM_TUNE_STATUS | | 21
9 | Odpověď na příkaz zjištění stavu ladění FM_TUNE_STATUS | | 22
10 | Příkaz zjištění stavu ladění FM_TUNE_STATUS | | 22
11 | Proměnná konfigurace příjmu RDS FM_RDS_CONFIG | | 23
12 | Příkaz přečtení přijaté RDS skupiny FM_RDS_STATUS | | 24
13 | Odpověď na příkaz přečtení přijaté RDS skupiny FM_RDS_STATUS | | 24
14 | Druhy USB přenosů | | 26
15 | Deskriptor zařízení | | 30
16 | Obecný formát deskriptorů řetězců | | 30
17 | Deskriptor konfigurace | | 31
18 | Deskriptor řídícího rozhraní zvuku | | 32
19 | Deskriptor řídícího rozhraní zvuku - hlavička | | 33
20 | Deskriptor řídícího rozhraní zvuku - vstupní terminál | | 34
21 | Deskriptor řídícího rozhraní zvuku - výstupní terminál | | 34
22 | Deskriptor rozhraní odesílání zvuku | | 35
23 | Deskriptor rozhraní odesílání zvuku | | 35
24 | Deskriptor formátu zvuku - hlavička | | 35
25 | Deskriptor formátu zvuku | | 36
26 | Deskriptor koncového bodu odesílání zvuku | | 37
27 | Deskriptor koncového bodu odesílání zvuku specifický pro danou třídu | | 38
28 | Deskriptor rozhraní USB - I²C tunelu | | 39
29 | Deskriptor koncových bodů USB - I²C tunelu | | 39
30 | Hlavička USB požadavků | | 43
31 | Formát požadavku USB - I²C tunelu | | 45
32 | Formát odpovědi USB - I²C tunelu | | 46

11

## 1 Úvod

Cílem této diplomové práce je navrhnout USB FM přijímač rádiového vysílání. Přijímač bude v systému reprezentován jako zvuková karta a bude obsahovat dva tunery. Jeden bude sloužit k samotnému příjmu vysílání a druhý k vyhledávání dalších stanic. Dále napsat knihovnu, umožňující ovládání tuneru pod Operačními systémy Linux a Windows. Text této práce je členěn do třech kapitol.
První kapitola se zabývá konstrukcí modulu. Je zde shrnuto a zhodnoceno několik možností jak realizovat jednak samotný příjem rozhlasového vysílání a také několik možností řešení napojení tunerů na USB sběrnici.
Druhá kapitola je věnována popisu vybraného tuneru. Je zde uveden zvolený způsob získání zvukových dat, filozofie ovládání tuneru a popis všech použitých příkazů pro tuneru.
Ve třetí kapitole je rozebráno napojení tunerů na USB sběrnici. Je zde pois USB popis porblémů s harmony , chyby v křemíku použitého MCU, porblémy nesynchronizovaných hodin udesílání zvuku. Popsáno vzniklé USB rozhraní (TODO)
Čtvrtá kapitola se věnuje vzniklé knihovně a demonstračnímu programu. V první části kapi-

toly je popis filozofie a rozvrstvení knihovny včetně popisu funkcí. Doplněno ukázkovým kódem práce. Závěru kapitoly je popsána demonstrační aplikace. (TODO)

12

## 2 Výběr součástek

Vzhledem k tomu, že není možné se cenou zařízení přiblížit zavedeným výrobcům elektroniky, rozhodl jsme se výběr součástek a konstrukci modulu přizpůsobit tak, aby bylo možné modul vyrobit v domácích podmínkách.

### 2.1 Způsob příjmu rozhlasového vyslání

Jednou možností je řešení přijímačem složeným z diskrétních součástek a nebo pomocí analogových IO. Ovšem toto je příliš komplikované.
Na trhu je řada integrovaných obvodů, které zajišťují samotný příjem vysílání včetně vyhledávání static, měření kvality signálu a přijmu RDS a to s minimem potřebných externích součástek. Tyto IO se typicky ovládají pomocí I²C nebo SPI a zvuk poskytují digitálně přes rozhraní I²S popřípadě analogově. Bohužel drtivá většina těchto IO je dostupná pouze v pouzdru

QFN, které se velmi obtížně pájí a je možné je sehnat pouze v minimálním množství 1000 kusů. Výjimkou je SI4735-D60 od výrobce SILICON LABS, který je dostupný v pouzdru SSOP24 a je možné jej u nás zakoupit i po jednotlivých kusech. IO neumožňuje přijímat DAB, ale umí

následující:

- Pásma: FM, SW, MW, LW.
- Vzorkovací frekvence až do 48kHz.
- Rozlišení vzorku kanálu až do 24bitů.
- Stereofonní příjem.
- Příjem RDS.

### 2.2 Volba rozhraní pro spojení modulu a počítače

Po tomto rozhraní se budou přenášet dva druhy informací a to samotný zvuk a ovládání tunerů. V současné době je prakticky jediným schůdným řešením použití rozhraní USB díky celé řadě výhod, které nabízí. Zejména jeho širokým rozšířením na téměř všech počítačích, od osobních přes servery až po jednodeskové či průmyslové počítače. Stejně tak je k dispozici velké množství součástek se zabudovanou podporou tohoto rozhraní. USB dále poskytuje možnost napájení připojených zařízení až do příkonu 2,5 W. Má zabudovanou podporu pro různé druhy přenosů včetně isochronních (garantovaný periodický přenos předem dohodnutého množství dat). Speci-

fikace USB zavádí standardní třídy funkcí v zařízení. V době psaní tohoto textu sice neexistuje třída pro ovládání tuneru, ale existuje třída popisující zvuková zařízení. Díky tomuto není potřeba vyvíjet vlastní ovladač zvukové karty na straně počítače.

13

### 2.2.1 Verze USB specifikací

V současné době je možné se setkat s USB verze 1.0, 1.1, 2.0 a 3.0. Dobrou zprávou je zpětná kompatibilita všech verzí. tj. zařízení podle specifikace 1.0 by mělo fungovat s jakýmkoliv hostem. Rychlost full speed definuje už první specifikace, její maximální propustnost 12 Mbit je pro věrný přenos dvoukanálového zvuku více než dostatečná. Novější verze nepřinášejí žádnou vlastnost, která by byla pro tento projekt přínosná.
Odlišná situace je v případě specifikací třídy USB audio. Existují vzájemně nekompatibilní verze 1.0 a 2.0. Ani zde mladší verze nepřináší žádný benefit, který bych mohl využít. Navíc doposud nemá nativní podporu ani ve Windows 10. Z tohoto důvodu není použití USB audio 2.0 příliš vhodné.

### 2.3 Napojení tuneru na USB

Požadavky:

- Schopnost přenášet dvoukanálový zvuk bez znatelného zkreslení. Zvolil jsem PCM formát

o vzorkovací frekvenci 48 kHz a rozlišení 16 bitů na jeden kanál. Pro srovnání audio CD používá 44,1 kHz / 16bitů.

- Alespoň jedno rozhraní I²S schopné přijímat zvuk a fungující v režimu master.
- Podporu pro USB audio. To implikuje nutnost podpory full speed USB a nebo rychlejší.

Low speed nepodporuje isochronní přenosy, které jsou nezbytné pro přenos zvuku.

- Rozhraní I²C master pro ovládání tunerů.
- Kompatibilita s 3,3 V logikou tunerů.

### 2.3.1 TAS1020b

Jak je patrné z obrázku 1, jedná se o USB I²S zvukovou kartu a MCU v jednom. Na rozdíl od většiny MCU nemá interní paměť programu. Program se načítá při spuštění buď z E²PROM paměti připojené přes I²C a nebo přes USB ze zařízení, ke kterému je obvod připojen.

Obvod podle specifikace [15] podporuje všechno potřebné. Full speed USB 1.1 včetně USB audio 1.0, 14 endpointů z toho až dva mohou být isochronní. Dále nabízí až dvě vstupní I²S rozhraní a jednu I²C sběrnici. Nevýhodou je absence programové paměti, kusová dostupnost obvodu

pouze ve formě vzorků a v mém případě také fakt, že s tímto druhem obvodů nemám žádné zkušenosti.

### 2.3.2 PIC16F1454

PIC16F1454 je osmi bitový MCU od firmy Microchip s podporou full speed USB 2.0. Obvod obsahuje továrně kalibrovaný oscilátor a umí pracovat při napájecím napětí 2,3-5,5V. Díky tomu

14

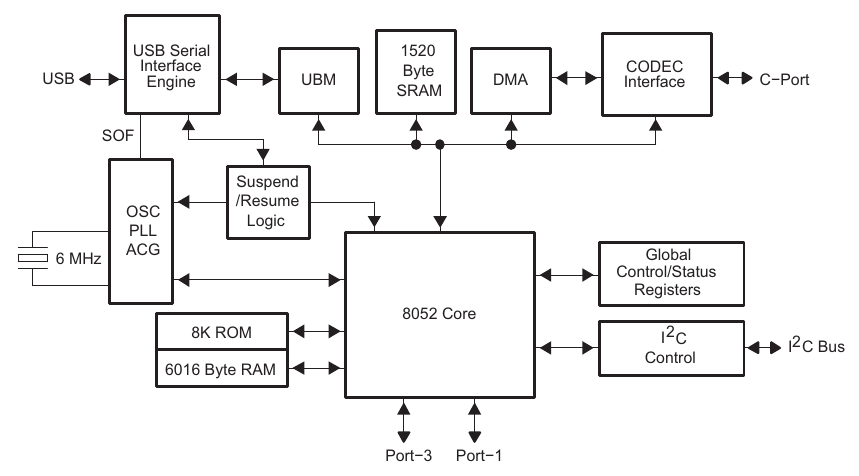
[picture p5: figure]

Obrázek 1: Blokové schéma TAS1020b. (Převzato z [15])

obvod nepotřebuje prakticky žádné externí součástky. V podstatě k němu stačí připojit pouze USB kabel.
Výrobce poskytuje k tomuto MCU knihovnu Microchip Library for aplications, která mimo jiné obsahuje implementaci USB audio 1.0. Navíc jedním ze vzorových projektů u této knihovny je i USB mikrofón, který řeší přenos zvuku do počítače.
Bohužel tento MCU nemá podporu I²S a na jeho softwarovou implementaci je příliš pomalý.

### 2.3.3 PIC32MX250F128

Tento 32 bitový MCU, taktéž od firmy Microchip, je vybaven všemi potřebnými rozhraními. Full speed USB 2.0, 2x nezávislé I²S , 2x I²C . Pracuje v rozmezí napájecích napětí 2,3-3,6V.

V MCU jsou k dispozici čtyři DMA kanály, které je možné řetězit (po ukončení jednoho kanálu se automaticky spustí druhý). Podobně jako u PIC16F1454 je i k tomuto čipu k dispozici framework Harmony [14] s podporou pro USB Audio 1.0. Vyrábí se v různých pouzdrech, dokonce

i v DIP, které je možné přímo zapojit do nepájivého pole.
Pro modul jsem vybral právě tento MCU. Případně je možné něco málo ušetřit a použít PIC32MX220F032. Liší se pouze menšími velikostmi pamětí, konkrétně 32kB programové paměti místo 128kB a 8kB datové paměti namísto 32kB.

15

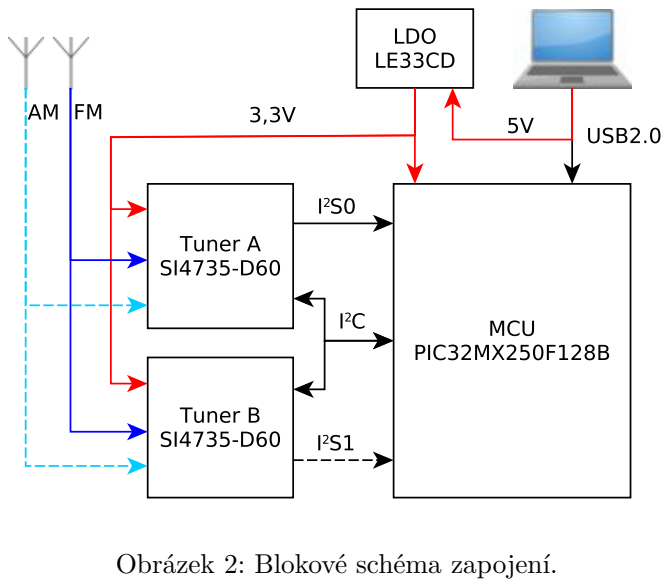
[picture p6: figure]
Obrázek 2: Blokové schéma zapojení.

### 2.4 Výsledná konstrukce

Propojení jednotlivých komponent je naznačeno na obrázku 2. Jak je patrné, zahrnul jsem i propojení tuneru B s MCU přes I²S a také vyvedení anténních AM vstupů tunerů (v obrázku

čárkovaně). Aktuálně nejsou využity, ale v budoucnu bude možné zařízení rozšířit o podporu

příjmu všech pásem, které tunery podporují a nebo přidat režim, kdy se modul bude chovat jako dvě nezávislé zvukové karty.
Celé zařízení je napájeno z USB přes jediný lineární stabilizátor LE33CD, který snižuje napájecí napětí na 3,3V. Dokáže poskytnout až 100mA a je odolný proti nadproudu a přehřátí [16]. MCU je zapojen podle doporučení v katalogovém listu [8] kapitola 2.1. Stejně tak tunery jsou zapojeny podle doporučení v katalogovém listu [6] kapitola 2.2.

Tady bych chtěl zmínit vstup RCLK. Tuner potřebuje v době ladění hodinový signál. V katalogovém listu je několikrát zmíněno, že tento signál je nutné buď přivést přímo na vstup RCLK a nebo se získá zapojením 32,768 kHz krystalu. Až v programovací příručce [7] v popisu parametru REFCLK_PRESCALE je možnost odvodit hodinový signál od vstupu hodinového signálu I²S

DCLK. Této možnosti jsem samozřejmě využil.
Kompletní schéma zapojení je součástí příloh.

16

## 3 Tuner

Jak jsem zmínil v kapitole 2.4 k přijmu rozhlasového vysílání je použit integrovaný obvod SI4735-D60. Zvuk je do MCU přenášen přes rozhraní I²S , samotné ovládání tuneru je realizováno přes sběrnici I²C .

### 3.1 Zvukové rozhraní I²S

MCU | Směr | Tuner | Význam
SDI | ⇒ | DOUT | Datový signál
SCK | ⇒ | DCLK | Hodiny
SS | ⇐ | DFS | Signál určení kanálu

Tabulka 1: Popis I²S signálů.

Rozhraní I²S je v případě jednosměrného přenosu v podstatě rozhraní SPI doplněné o další

datový signál. Význam signálů včetně odpovídajících názvů pinů na MCU a tuneru shrnuje tabulka 1. V případě I²S se nejedná o sběrnici. Vždy komunikují právě dvě zařízení kde jedno je

master a druhé slave. Master vždy vysílá datový signál a signál přepínání kanálů. Datový signál vysílá samozřejmě zřízení, které je zdrojem zvuku. Je možný i obousměrný přenos, potom je nutné použití dvou datových linek.
Tuner umí pracovat pouze v režimu slave, takže hodinový signál a signál přepínání kanálů je generován z MCU. Vzorkování zvuku v tuneru je řízeno jeho vlastním interním oscilátorem. Díky tomuto pravděpodobně občas dojde k zahození některého vzorku pokud MCU čte pomaleji než tuner provádí vzorkování, a nebo dojde k přečtení náhodných dat v opačném případě. Nicméně v praxi jsem s tímto nezaznamenal žádný problém.
Vyjma standardního formátu dat popsaného v I²S specifikace [18] vzniklo ještě několik dalších

formátů. Použil jsem standardní formát, tak jak je zobrazen na obrázku 3.

### 3.2 Ovládací rozhraní I²C

Ovládání tuneru se provádí přes rozhraní I²C . Toto rozhraní je součástí drtivé většiny mikrokontrolérů, není ho třeba blíže popisovat. Tuner se do režimu I²C přepne připojením pinů GPO1

na napájecí napětí a GPO2 k zemi.

SEN | Adresa čtení | Adresa zápisu
0 | 0x23 | 0x22
1 | 0xC7 | 0xC6

Tabulka 2: I²C adresy.

17

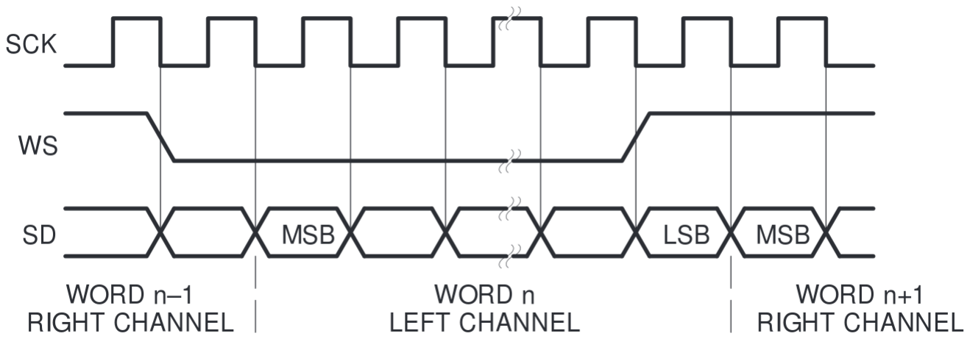
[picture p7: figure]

Obrázek 3: Časový diagram I²S přenosu. (Převzato z [18])

Základní informací nezbytnou pro komunikace s tunerem je I²C adresa. Tuner umožňuje

změnu adresy pomocí změny úrovně na pinu SEN. Adresy jsou v tabulce 2.

### 3.3 Ovládání tuneru

Tuner se ovládá zapisováním příkazů a případným čtením odpovědí. Dále je zde dvojice příkazů pro čtení a zápis proměnných. (properties) tuneru. Kompletní popis všech příkazů a proměnných je v programovací příručce k tuneru [7].

Název pole | Délka
CMD | 1 B | Příkaz.
ARG1 - ARG7 | 0 - 7 B | Případný argument příkazu.

Tabulka 3: Formát příkazu pro tuner.

Název pole | Délka
STATUS | 1 B | Status tuneru.
RESP1 - RESP15 | 0 - 15 B | Případná další data odpovědi.

Tabulka 4: Formát odpovědi tuneru.

Všechny příkazy mají jednotný formát vyobrazený v tabulce 3. Každý příkaz je jednou transakcí zápisu na I²C sběrnici. Případnou odpověď na příkaz je možné získat následnou transakcí čtení z I²C sběrnice. Formát odpovědi je v tabulce 4. Jak je patrné odpověď na každý příkaz

obsahuje vždy minimálně jeden byte se stavem zařízení (STATUS). Význam jednotlivých bitů

v tomto byte je následující:

- Bit 7 CTS - Pokud je v 1 je možné do tuneru odeslat další příkaz.
- Bit 6 ERR - Pokud je v 1 signalizuje chybu provádění příkazu.
- Bity 5 - 3 Rezervováno - Hodnoty těchto bitů nejsou specifikovány.

18

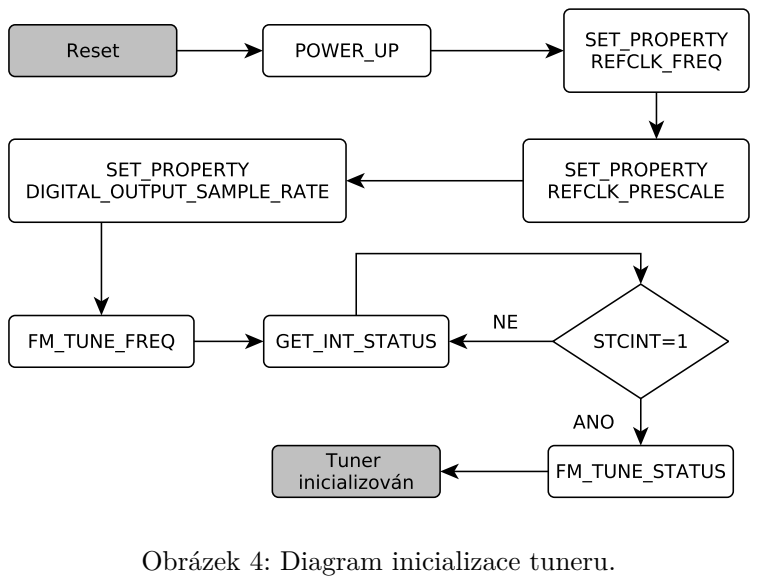
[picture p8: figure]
Obrázek 4: Diagram inicializace tuneru.

- Bit 2 RDSINT - Pokud je v 1 signalizuje vznik přerušení od přijmu RDS.
- Bit 1 ASQINT - Pokud je v 1 signalizuje dokončení měření parametrů přijmu.
- Bit 0 STCINT - Pokud je v 1 signalizuje dokončení ladění nebo vyhledávání stanice.

Bity CTS a ERR se aktualizují vždy. Pro čtení nejnižších třech bitů je potřeba aktualizovat jejich hodnoty příkazem GET_INT_STATUS. Tento příkaz má číslo 0x14 a nemá žádné argumenty. Tuner umožňuje nakonfigurovat signalizaci změny některého z těchto bitů změnou úrovně na výstupu GPO2/INT. Této možnosti jsem se ale rozhodl nevyužít.

Jak jsem zmínil výše, kromě příkazů se parametry tuneru nastavují a nebo čtou pomocí proměnných. jedná se vždy o 16-ti bitové hodnoty, které se identifikují taktéž 16-ti bitovým číslem.
Zápis hodnoty se provádí příkazem SET_PROPERTY (0x12), za kterým následuje jeden

nulový byte, za ním horní a poté dolní byte čísla proměnné. Dále se vyšle horní byte a poté dolní byte vlastní hodnoty.
Čtení se provádí obdobně, příkazem GET_PROPERTY (0x14) za kterým se vyšle nulový

byte následovaný horním a dolním byte čísla zapisované proměnné. Hodnota se získá následným čtením z I²C sběrnice. Horní byte hodnoty je až ve druhém bytu argumentu ARG-2 (viz. tab. 4),

dolní byte v je v ARG-3.

### 3.3.1 Inicializace tuneru

Po spuštění MCU vždy provádí inicializaci obou tunerů. Průběh inicializace shrnuje diagram 4. Z důvodu zkrácení doby spuštění modulu probíhá inicializace formou jednoduchého "multitaskingu". Pokud je jeden tuner zaneprázdněn testuje se stav druhého tuneru a v případě, že

19 není zaneprázdněn dojde k vyslání příkazu, pokud je zaneprázdněn testuje se znova první tuner a tak dále. Ze stejného důvodu je v příkazu FM_TUNE_STATUS nastaven příznak zrychleného

nepřesného ladění.

Bit | 7. | 6. | 5. | 4. | 3. | 2. | 1. | 0.
CMD | 0x01
ARG1 | CTSIEN = 0 | GPO2OEN = 0 | PATCH = 0 | XOSCEN = 0 | FUNC = 0
ARG2 | OPMODE = 0b10110000

Tabulka 5: Příkaz spuštění tuneru POWER_UP.

Inicializace začíná spuštěním tuneru příkazem POWER_UP. Formát příkazu je v tabulce 5. Součástí příkazu jsou tyto parametry:

- CTSIEN - Možnost hardwarové signalizace přerušení v okamžiku kdy je možné odeslat

další příkaz. Hardwarové přerušení nepoužívám.

- GPO2OEN - Nastavení pinu GPO2 jako výstupu.
- PATCH - Umožňuje načtení novějšího firmware do integrovaného obvodu tuneru.
- XOSCEN - Použití krystalu jako zdroje hodinové frekvence. Místo krystalu používám přímo hodinový kmitočet rozhraní I²S .
- FUNC - Použitá hodnota nastaví režim přijmu FM rádia.
- OPMODE - Nastavení výstupu zvuku. Význam hodnoty v tabulce určuje, že bude použit pouze digitální výstup zvuku I²S .

Odpovědí na tento příkaz je pouze jeden byte se statusem tuneru.
Dále je potřeba nastavit dvě proměnné. REFCLK_PRESCALE hodnotu děličky hodinového kmitočtu a do REFCLK_FREQ výslednou frekvenci, která se musí pohybovat v rozsahu 31, 130 − 34, 406Khz. Jak už jsem zmínil jako zdroj hodinové frekvence je použita hodinová frekvence I²S rozhraní. Tato frekvence vyplývá ze součinu počtu kanálů, jejich rozlišení a vzor-

kovací frekvence. 2 · 16 · 48 = 1536kHz. Dělící poměr tedy vychází 1536/32 = 48 při frekvenci

32000kHz.
Zatímco REFCLK_FREQ obsahuje pouze 16-ti bitovou hodnotu frekvence v Hz v RE-FCLK_PRESCALE jsou pro hodnotu dělícího poměru vyhrazeny bity 0-11. Bity 13-15 musí být nulové, bit 12 je nastaven na hodnotu 1, což znamená, že se jako zdroj hodinové frekvence použije I²S .

Poslední proměnná, kterou je potřeba nastavit, je DIGITAL_OUTPUT_SAMPLERATE. Obsahuje hodnotu vzorkovací frekvence. V tomto případě je to hodnota 48000.
Proměnné se nastavují pomocí příkazu SET_PROPERTY popsaného v kapitole 3.3. Výsledné hodnoty a čísla proměnné jsou shrnuty v tabulce 6.

20

Název | Číslo | Hodnota
REFCLK_FREQ | 0x0201 | 0x7D00
REFCLK_PRESCALE | 0x0202 | 0x102A
DIGITAL_OUTPUT_SAMPLE_RATE | 0x0104 | 0xBB80

Tabulka 6: Proměnné použité pro inicializaci tuneru.

Bit | 7. | 6. | 5. | 4. | 3. | 2. | 1. | 0.
CMD | 0x20
ARG1 | 0x00 | | | | | | FREEZE = 0 | FAST = 1
ARG2 | FREQH = 0x24
ARG3 | FREQL = 0x94
ARG4 | ANTCAP = 0x00

Tabulka 7: Příkaz spuštění tuneru FM_TUNE_FREQ.

Poslední částí inicializace tuneru je naladění frekvence 93,7 MHz příkazem FM_TUNE_FREQ. Formát příkazu včetně použitých hodnot je v tabulce 7. Význam parametrů je následující:

- FREEZE - Nastavení způsobí pozvolný přechod zvuku po přeladění.
- FAST - Nastavení způsobí rychlé ale nepřesné přeladění.
- FREQH - Horní byte frekvence v desetinách MHz.
- FREQL - Dolní byte frekvence v desetinách MHz.
- ANTCAP - Nastavení kapacity vstupního kondenzátoru antény. Hodnota 1-191 pF. Hod-

nota 0 znamená automatické nastavení.

Odpovědí na tento příkaz je pouze jeden byte obsahující status tuneru. Dokončení ladění je signalizováno nastavením bitu STCINT ve statusu. K aktualizaci hodnoty tohoto bytu je nutné vždy vyslat příkaz GET_INT_STATUS. Tento příkaz se skládá z jediného byte s číslem příkazu 0x14. Odpovědí na tento příkaz je rovněž jediný byte se statusem tuneru kde jsou aktualizovány hodnoty bitů signalizujících přerušení RDSINT, ASQINT a STCINT.

Bit | 7. | 6. | 5. | 4. | 3. | 2. | 1. | 0.
CMD | 0x22
ARG1 | 0x00 | | | | | | CANCEL = 0 | INTACK = 1

Tabulka 8: Příkaz zjištění stavu ladění FM_TUNE_STATUS.

Ke smazání bitu STCINT je použit příkaz FM_TUNE_STATUS viz. tabulka 8. Kromě smazání tohoto bitu nastavením parametru INTACK je možné nastavením tohoto parametru

21

Bit | 7. | 6. | 5. | 4. | 3. | 2. | 1. | 0.
SATUS | CTS | ERR | X | X | RSQINT | RDSINT | X | STCINT
RESP1 | BLTF | X | X | X | X | X | AFCRL | VALID
RESP2 | READFREQH
RESP3 | READFREQL
RESP4 | RSSI
RESP5 | SNR
RESP6 | MULT

Tabulka 9: Odpověď na příkaz zjištění stavu ladění FM_TUNE_STATUS.

zrušit probíhající ladění nebo vyhledávání stanice. Jak je vidět z tabulky 9, odpověď na příkaz obsahuje kromě statusu tuneru následující informace:

- BLTF - Je nastaven pokud vyhledávání stanice přeteklo přes hodnotu maximální nebo

podteklo hodnotu minimální laditelné frekvence.

- AFCRL - Je nastaven pokud je automatické dolaďování aktivní.
- VALID - Naladěná frekvence byla vyhodnocena jako validní.
- READFREQH - Horní byte naladěné frekvence v desetinách MHz.
- READFREQL - Dolní byte naladěné frekvence v desetinách MHz.
- RSSI - Indikátor síly přijímaného signálu v dBµV.
- SNR - Odstup signálu od šumu v dB.
- MULT - Indikátor míry odrazů v signálu.

### 3.3.2 Vyhledávání stanic

Bit | 7. | 6. | 5. | 4. | 3. | 2. | 1. | 0.
CMD | 0x22
ARG1 | 0x00 | | | | SEEKUP | WRAP | 0x00

Tabulka 10: Příkaz zjištění stavu ladění FM_TUNE_STATUS.

Vyhledávání stanic se provádí pomocí příkazu FM_SEEK_START popsaném v tabulce 10. Příkaz lze parametrizovat pouze pomocí dvou bitů. Nastavením bitu SEEKUP se bude vyhledávat směrem k vyšším frekvencím. Nastavením bitu WRAP bude při dosažení nejvyšší frekvence vyhledávání pokračovat znova od nejnižší frekvence, v případě sestupného vyhledávání se bude

22 po dosažení nejnižší frekvence pokračovat od horní frekvence. Pokud bit WRAP není nastaven, při dosažení nejnižší nebo nejvyšší frekvence dojde k zastavení vyhledávání.
Ukončení vyhledávání je signalizováno nastavením bitu STCINT ve statusu odpovědi tuneru. Detekce ukončení vyhledávání se provádí shodně jako detekce ukončení ladění popsaná v kap. 3.3.1. Naladěnou frekvenci a informace o kvalitě signálu je možné přečíst příkazem FM_TUNE_STATUS, který byl taktéž popsán v kapitole 3.3.1. Tyto informace se vždy aktualizují po naladění, opětovné volání příkazu FM_TUNE_STATUS vrací vždy stejné hodnoty.

### 3.3.3 Čtení RDS z tuneru

RDS je rozšíření pozemního rozhlasového vysílání o souběžné vysílání různých digitálních informací. Z nejznámějších informací je to RT (Radio Text) - přenos až 64 znaků textu, typicky s názvem právě přehrávané skladby a nebo názvem rádiové stanice. Potom AF (Alternative frequency) seznam dalších frekvencí, na kterých je možné stanici naladit, což lze s využitím informace PI (Programme Identification), který stanici jednoznačně identifikuje k automatickému přelaďování na frekvenci s lepším příjmem. Kompletní popis je v [19].

Proud přenášených dat se dělí do třiceti skupin označených 1A, 1B, 2A ... 15A, 15B. Každá skupina má pevně danou velikost 104 bitů a skládá se ze čtyř stejně dlouhých bloků. Chtěl bych upozornit, že v normě [19] jsou tyto bloky označeny čísly 1 až 4, kdežto v programovací příručce tuneru [7] jsou označeny písmeny A až D. Každý blok nese 16 bitů užitečných dat a

10-ti bitové kontrolní slovo. Vyhodnocování chyb v přijatých datech a jejich případnou korekci zajišťuje tuner. Pro příjem je v tuneru k dispozici fronta na 14 skupin.

Bit | 15. | 14. | 13. | 12. | 11. | 10. | 9. | 8.
Horní byte | BLETHA = 2 | | BLETHB = 2 | | BLETHC = 2 | | BLETHD = 2
Bit | 7. | 6. | 5. | 4. | 3. | 2. | 1. | 0.
Dolní byte | 0x00 | | | | | | | RDSEN = 1

Tabulka 11: Proměnná konfigurace příjmu RDS FM_RDS_CONFIG.

Příjem RDS v tuneru je potřeba nejprve nakonfigurovat a povolit. Díky nepoužití hardwarového přerušení, je možné konfiguraci přerušení přeskočit. Konfigurace přijmu RDS se zjednoduší na nastavení jediné proměnné FM_RDS_CONFIG, jejíž formát se nachází v tabulce 11. Nastavením bitu RDSEN této proměnné dojde k povolení přijmu RDS. Pole BLETHA až BLETHD specifikují dovolenou míru chybovosti bloků A až D přijímaných skupin a to takto:

- 0 - Pokud je v bloku jakákoliv chyba celá skupiny bude zahozena.
- 1 - Skupina bude přijata, pokud v bloku došlo k opravě nejvýše dvou bitů.
- 2 - Skupina bude přijata, pokud v bloku došlo k opravě nejvýše pěti bitů.
- 3 - Jakékoliv, i neopravitelné, množství chyb v bloku nezpůsobí zahození skupiny.

23

Bit | 7. | 6. | 5. | 4. | 3. | 2. | 1. | 0.
CMD | 0x24
ARG1 | 0x00 | | | | | STATUSONLY = 0 | 0x00 | INTACK = 1

Tabulka 12: Příkaz přečtení přijaté RDS skupiny FM_RDS_STATUS.

Vyčítání přijatých skupin se potom provádí příkazem FM_RDS_STATUS, uvedeným v tabulce 12. Nastavením bitu STATUSONLY v argumentu tohoto příkazu je možné pouze vyčíst informace o stavu příjmu RDS bez odebrání nejstarší přijaté skupiny z fronty. Nastavením druhého bitu INTACK dojde ke smazání příznaku přerušení RDSINT ve statusu tuneru. Vzhledem k nepoužití přerušení nastavení bitu INTACK nemá význam.

Bit | 7. | 6. | 5. | 4. | 3. | 2. | 1. | 0.
SATUS | CTS | ERR | X | X | RSQINT | RDSINT | X | STCINT
RESP1 | X | X | RDSNEW BLOCKB | RDSSYNC BLOCKA | X | RDSSYNC FOUND | RDSSYNC LOST | RDSRECV
RESP2 | X | X | X | X | X | GRPLOST | X | RDSSYNC
RESP3 | RDSFIFOUSED
RESP4 | BLOCKAH
RESP5 | BLOCKAL
RESP6 | BLOCKBH
RESP7 | BLOCKBL
RESP8 | BLOCKCH
RESP9 | BLOCKCL
RESP10 | BLOCKDH
RESP11 | BLOCKDL
RESP12 | BLEA | | BLEB | | BLEC | | BLED

Tabulka 13: Odpověď na příkaz přečtení přijaté RDS skupiny FM_RDS_STATUS.

Odpověď na tento příkaz v tabulce 13 je podle očekávání poněkud obsáhlejší. První byte obstahuje jako vždy status tuneru. V následujících dvou bytech za statusem jsou bity jejihž LOG 1 má následující význam:

- RDSNEWBLOCKB, RDSNEWBLOCKA - Byl přijat validní blok B nebo A.
- RDSSYNCFOUND - Příjem RDS je synchronizován.
- RDSSYNCLOST - Ztracena synchronizace příjmu RDS, např. z důvodu špatného sig-

nálu.

- RDSRECV - Nastaven pokud je ve frontě počet skupin větší nebo roven hodnotě pro-

měnné FM_RDS_INT_FIFO_COUNT. Tato proměnná byla ponechána ve výchozím nastavení na hodnotě 0, takže tento bit bude nastaven vždy.

- GRPLOST - Přetečení fronty přijatých skupin.

24

- RDSSYNC - Příjem RDS je synchronizován. (Aktuální stav.)

V bytu RDSFIFOUSED je počet skupin ve frontě. Pokud je tato hodnota větší než nula, v následujících osmi bytech se nachází data nejstarší přijaté skupiny. V posledním byte odpovědi jsou informace o chybovosti přijmu jednotlivých bloků skupiny BLEA až BLED. Význam hodnot

chybovosti je tento:

- 0 - Blok přijat bez chyby.
- 1 - V bloku došlo k opravě jednoho až dvou bitů.
- 2 - V bloku došlo k opravě tří až pěti bitů.
- 3 - Blok nebylo možné opravit. Neobsahuje platná data.

Aby nedoházelo k přetečení fronty přijatých skupin, je potřeba frontu vyčítat v dostatečně

krátkých intervalech. Zde je možné využít z pevné délky skupiny 104 b a rychlosti přenosu 1187,5 kHz. Přenos skupiny tedy trvá 87,5 ms. K naplnění 14-ti prvkové fronty tedy dojde nejdříve za 1,2 s. Pokud bude interval vyčítání vždy kratší, k přetečení fronty nedojde.

25

## 4 USB

Na rozdíl od například populárního rozhraní UART je USB podstatně komplikovanější. Je to určitou daní za jeho univerzálnost. Vzhledem k velkému rozsahu specifikace USB [2] se omezím

pouze na popis částí nezbytných pro implementaci modulu.
S vydáním specifikace USB 2.0 byly předchozí specifikace označeny jako zastaralé a neměly by se používat pro nové konstrukce. Následující text se tedy týká USB 2.0 a rychlosti full-speed.

### 4.1 Stručný úvod do full-speed USB 2.0

### 4.1.1 Topologie

Ačkoliv název rozhraní (Univerzální Sériová Sběrnice) napovídá, že jde o sběrnici, jedná se o

zapojení typu hvězda. Přesněji, jak je vidět z obrázku 5, připojená zařízení a rozbočovače tvoří strom jehož kořenem je hostitel. Tento implementuje tzv. kořenový rozbočovač (root hub), ke

kterému je možné buď přímo připojit jedno zařízení a nebo rozbočovač a do něj dalších až osm zařízení/rozbočovačů. Je možné takto za sebe zřetězit až pět rozbočovačů. Celkově je možné na jeden kořenový rozbočovač připojit až 127 zařízení (včetně rozbočovačů).

Velkou výhodou je, že zařízení je od topologie odstíněno. Vždy se z jeho pohledu komunikuje přímo s hostem. Ve specifikaci je také zohledněn fakt, že zařízení zpravidla nezastává pouze jedinou funkci. To je konec konců případ i tohoto modulu. Obsahuje dvě funkce - zvukovou kartu a I²C tunel pro komunikaci s tunery.

### 4.1.2 Komunikace

| Latence | Vyhrazená šířka pásma | Spolehlivý přenos | Typ dat
Isochroní přenos | Minimální | až 90% | Ne | Proud
Hromadný přenos | Negarantovaná | Ne | Ano | Proud
Přenos přerušení | Minimální | až 90% | Ano | Proud
Řídící přenos | Negarantovaná | až 10% | Ano | Zprávy

Tabulka 14: Druhy USB přenosů.

Aby bylo možné uspokojit nároky na přenos (transfer) dat rozdílné povahy různými funkcemi, zavádí specifikace koncové body (endpoint). Osm výstupních (OUT) pro směr z hostitele do zařízení a osm pro směr opačný (IN). Směr je vždy určován právě z pohledu hostitele. Každému

bodu je možné přiřadit jeden ze čtyř druhů přenosu podle tabulky 14. Výjimkou je vstupní a výstupní koncový bod nula. Tyto vždy slouží pro řídící přenosy a na rozdíl od ostatních bodů je musí podporovat všechna zařízení.
Full-speed USB podporuje čtyři druhy komunikace uvedené v tabulce 14.

26

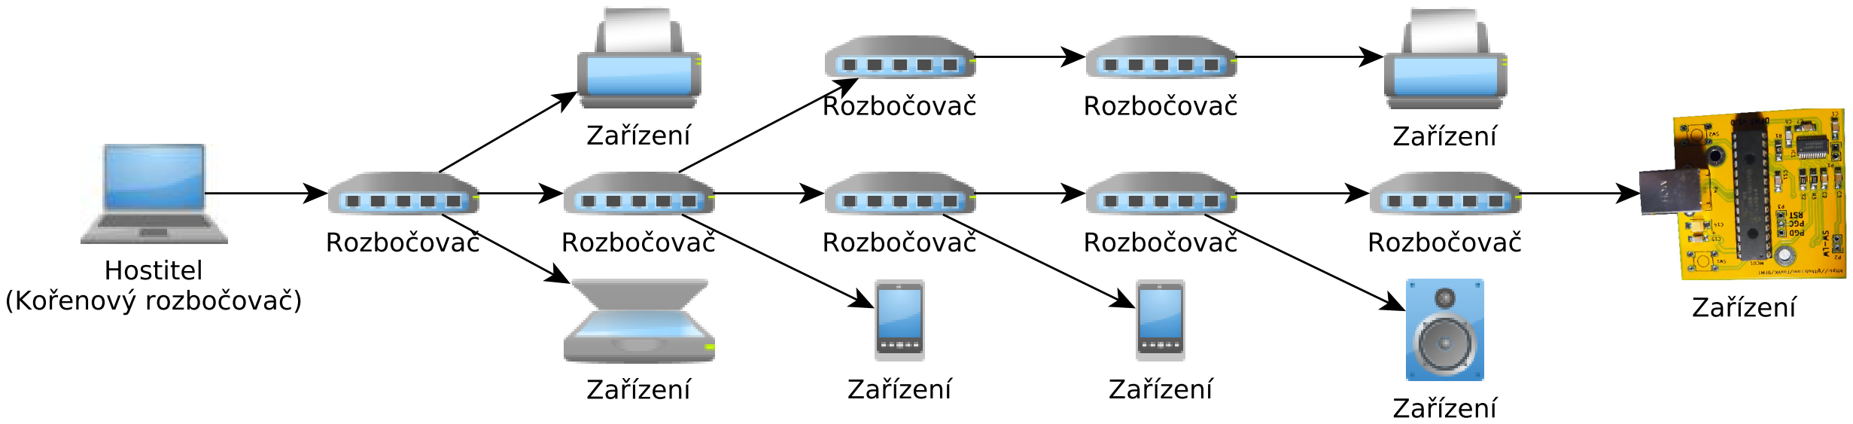
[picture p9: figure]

Obrázek 5: Příklad topologie USB sběrnice.

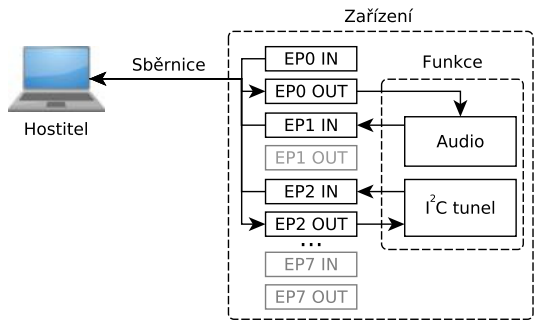
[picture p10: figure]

Obrázek 6: USB koncové body a funkce.

Body nula jsou využívány jednak k inicializaci a správě vlastního zařízení, ale také můžou být využívány zároveň i funkcemi. Například popisovaný modul jej využívá pro ovládání audio funkce. Modul dále využívá vstupní koncový bod 1 pro přenos zvuku do hostitele a potom dvojici koncových bodů 2 v obou směrech pro komunikaci s tunery viz. obrázek 6.
Přenos vždy sestává z alespoň jedné transakce (transaction), která se dále dělí na pakety (packets). Transakce je z pohledu zařízení vždy vyřizována od počátku do konce bez přerušení

jinou transakcí. Je vždy iniciována vysláním token paketu hostitelem, který takto může řídit šířku pásma přidělovanou jednotlivým zařízením na sběrnici. Token pakety mohou být podle druhu transakce následujících třech druhů:

- IN (Vstupní) - Následuje přenos ze zařízení do hostitele.
- OUT (Výstupní) - Následuje přenos z hostitele do zařízení.
- SETUP - Následuje řídící přenos.

Za tímto paketem následuje nula nebo více paketů s daty. Aby bylo možné detekovat výpadek nebo duplikaci některého z paketů jsou specifikovány hned dva typy paketů. A to DATA0 a DATA1. U izochronních transakcí se vždy posílají pakety DATA0. U ostatních transakcí se vyšle nejprve DATA0 a poté se tyto druhy paketů střídají nezávisle na transakcích. Znovu se od DATA0 začne pouze v následujících případech:

27

- Na začátku každé řídící transakce.
- Po následujících žádostech hostitele (bude popsáno dále):

– Přiřazení konfigurace.

– Zrušení zastavení koncového bodu.

– Nastavení rozhraní.

Za datovými pakety následuje potvrzování transakce protistranou. Izochronní přenosy potvrzování nepodporují, tudíž datovými pakety jejich transakce končí. Transkace hromadných přenosů a přenosu přerušení jsou vždy zakončeny jedním potvrzovacím (handshake) paketem. Transkace řídících přenosů mají před potvrzovací paket vložen jeden datový paket nulové délky (zero length packet často zkracovaný ZLP), ale opačného směru než všechny předchozí datové pakety.

Potvrzovací paket vždy vysílá zařízení. Má vždy jeden z následujících typů:

- ACK (Úspěch) - Úspěšné ukončení transakce.
- NAK (Neúspěch) - Typicky poškozená přijímaná data a nebo častěji zařízení nemá při-

pravena data k odeslání.

- STALL (Chyba) - Zařízení takto reaguje na požadavek, který nepodporuje.

Rozdíl mezi NAK a STALL je, že po NAK potvrzení bude hostitel požadavek opakovat (počet opakování není explicitně specifikován), kdežto STALL signalizuje nemožnost vyřízení požadavku

a tudíž jej opakovat nemá smysl.
Formátování a rozpoznávání paketů řeší přímo USB modul v mikrokontroléru, není tedy nutné se jím hlouběji zabývat. Detailní popis je v kapitole 8 USB specifikace [2].

### 4.1.3 Deskriptory

USB specifikace zavádí deskriptory (descriptors). Jedná se o unifikovaný způsob jak může zařízení

informovat hostitele o svých schopnostech a požadavcích. Na základě právě těchto informací může operační systém vybrat pro funkce zařízení odpovídající ovladače, řadič v hostiteli se dozví kolik dat, jak často bude přenášet po jednotlivých koncových bodech a jakou má tomuto přenosu přiřadit prioritu a podobně.
Při vývoji zařízení je základním rozdělením deskriptorů rozdělení podle požadavků hostitele:
- Deskriptor zařízení (Sevice descriptor) - Nejnutnější informace pro správu zařízení

na sběrnici.

- Deskriptory řetězců (String dscriptors) - Pole textových řetěců a informace o dostup-

ných lokalizacích.

- Deskriptory konfigurace (Configuration descriptor) - Struktura deskriptorů s veškerými

dalšími informacemi.

28

Popis všech deskriptorů všech možných funkcí je zcela mimo rozsah tohoto textu. Dále se omezím pouze na deskriptory a jejich hodnoty použité v modulu.

### 4.1.4 Deskriptor zařízení

Název pole | Délka | Hodnota
bLength | 1B | 18 | Délka deskriptoru.
bDescriptorType | 1B | 0x01 | Typ deskriptoru.
bcdUSB | 2B | 0x0200 | Verze USB specifikace implementovaná zařízením. (2.0)
bDeviceClass | 1B | 0x00 | Třída zařízení.0x00 znamená, že třídu specifikuje každé rozhraní zvlášť.
bDeviceSubClass | 1B | 0x00 | Podtřída zařízení. Pokud je bDeviceClass 0x00, musí být i toto pole 0x00.
bDeviceProtocol | 1B | 0x00 | Protokol zařízení. Pokud je bDeviceClass 0x00, musí být i toto pole 0x00.
bMaxPacketSize | 1B | 64 | Největší délka data, kterou je možné odeslat koncovým bodem 0.
idVendor | 2B | 0x04D8 | ID výrobce zařízení.
idProduct | 2B | 0xF32C | ID zařízení.
bcdDevice | 2B | 0x0100 | Verze zařízení 1.0.
iManufacturer | 1B | 1 | Odkaz na řetězec s názvem výrobce.
iProduct | 1B | 2 | Odkaz na řetězec s názvem zařízení.
iSerialNumber | 1B | 0 | Odkaz na řetězec se sériovým číslem zařízení. 0 znamená nespecifikován.
bNumConfigurations | 1B | 1 | Počet konfigurací zařízení.

Tabulka 15: Deskriptor zařízení.

V tabulce 15 je uveden deskriptor zařízení tak, jak je použit v modulu. Myslím, že popis významu polí v tabulce je dostatečný. Za zmínku stojí ID výrobce a zařízení. Jejich účel je stejný jak například MAC adresa síťových zařízení a to jednoznačně identifikovat druh zařízení. Oficiální cesta je požádat o přiřazení ID výrobce USB implementers fórum, což v době psaní toho textu stojí 5000 amerických dolarů [17]. Výrobci programovatelných součástek s podporou

USB, ale naštěstí zpravidla nabízejí možnost zdarma získat ID zařízení z jejich rozsahů. Jednou z podmínek bývá nutnost použít přidělení ID právě na jejich součástce. Pro modul jsem získal ID produktu od firmy Microchip 0xF32C. ID výrobce je 0x04D8.
Pole iManufacturer, iProduct a iSerialNumber nesou indexy na deskriptory textových řetězců. Všechna pole jsou nepovinná. V případě jejich vynechání se použije index s hodnotou
0. Jak napovídají názvy jednotlivých polí, je možné takto přidat popisek výrobce a zařízení ve formě lidsky čitelného textu a sériové číslo daného kusu zařízení, které může využít ovladač v hostiteli například pro načtení posledního nastavení po opětovném připojení zařízení.

29

### 4.1.5 Deskriptory řetězců

Byte | 1. bLength | 2. bDescriptorType | 3. | 4. | 5. | 6. | 2N+1 | 2N+2
Index 0 | 2N+2 | 0x03 | wLANGID[0] | | wLANGID[1] | | wLANGID[N]
Index 1 | 2N+2 | 0x03 | Znak 0 | | Znak 1 | | Znak N

Tabulka 16: Obecný formát deskriptorů řetězců.

Deskriptory řetězců jsou organizovány jako pole indexované od nuly. Každý jeden řetězec začíná hlavičkou deskriptoru, ve které je určen typ deskriptoru a jeho celková délka v bytech. Poté následuje samotný text zakódovaný podle normy unicode, konkrétně UTF-16. Je tedy možné použití i národních znaků.
Jedinou výjimkou je deskriptor s indexem 0. V zařízení je možné mít více sad textů v různých jazycích. Seznam dostupných jazyků (jazykových kódů) je právě v tomto deskriptoru. Seznam těchto kódů popisuje [5]. V modulu jsem se omezil pouze na angličtinu (kód 0x0409). Obecný

formát těchto deskriptorů je naznačen v tabulce 16.

### 4.1.6 Konfigurace zařízení

Konfigurace zařízení je soubor deskriptorů, který popisuje schopnosti zařízení a také jeho nároky na přenos, popřípadě definují sady parametrů z nichž si může hostitel vybrat tu, která mu v daný okamžik nejvíce vyhovuje. Zařízení musí specifikovat minimálně jednu konfiguraci, ale také více. Hostitel potom zařízení jednu přidělí, případně ji může kdykoliv změnit za jinou.
Každá jedna konfigurace začíná deskriptorem konfigurace, za kterým následují deskriptory rozhraní a koncových bodů, do kterých mohou být zanořeny deskriptory další. Tvoří takto stromovou strukturu. V případě mého modulu je možná pouze jediná konfigurace. Její struktura vypadá následovně:
1. Deskriptor řídícího rozhraní zvuku.
(a) Deskriptor řídícího rozhraní zvuku - hlavička.
(b) Deskriptor řídícího rozhraní zvuku - vstupní terminál přijímač rádia.
(c) Deskriptor řídícího rozhraní zvuku - výstupní terminál odesílání zvuku přes USB.
2. Deskriptor rozhraní pro odesílání zvuku - varianta s vypnutým přenosem.
3. Deskriptor rozhraní pro odesílání zvuku - varianta se zapnutým přenosem.
(a) Deskriptor rozhraní pro odesílání zvuku - obecný deskriptor.
(b) Deskriptor rozhraní pro odesílání zvuku - popis formátování dat.
(c) Deskriptor koncového bodu - odesílání zvuku.

30

4. Deskriptor rozhraní specifikovaného výrobcem - I²C tunel.
(a) Deskriptor koncového bodu - odesílání dat hostu.
(b) Deskriptor koncového bodu - příjem dat z hosta.

### 4.1.7 Deskriptor konfigurace

Název pole | Délka | Hodnota
bLength | 1B | 9 | Délka deskriptoru.
bDescriptorType | 1B | 0x02 | Typ deskriptoru.
wTotalLength | 2B | 127 | Celková délka všech deskriptorů konfigurace.
bNumInterfaces | 1B | 3 | Počet rozhraní v konfiguraci.
bConfigurationValue | 1B | 1 | Index této konfigurace.
iConfiguration | 1B | 0 | Odkaz na řetězec s popisem konfigurace.
bmAttributes | 1B | 0b10000000 | Bitová maska s atributy.

Tabulka 17: Deskriptor konfigurace.

Jak je vidět z tabulky 17, tento deskriptor obsahuje informace pro identifikaci konfigurace. A to zejména index iConfiguration. To je hodnota, kterou poté pošle host do zařízení v požadavku o přidělení konfigurace. Dále následuje pole wTotalLength s celkovou délkou konfigurace. Hostitel obdrží všechny případné konfigurace v jednom bloku. Na základě této hodnoty rozliší, kde jednotlivé konfigurace začínají a končí.
Za zmínku také stojí pole bmAttributes. Nejvyšší bit musí být z důvodu kompatibility s USB

1.0 nastaven na 1, nejnižší bity 0-4 jsou rezervovány pro budoucí použití a musí být nastaveny na 0. Bit 6 signalizuje, že zařízení není napájeno z USB sběrnice. Bit 5 signalizuje, že zařízení chce využívat mechanizmus vlastního probuzení a informování hostitele o události. Modul má oba atributy nastaveny na hodnotu 0.

### 4.1.8 Deskriptory konfigurace vztažené k USB audio 1.0

Největší část konfigurace zabírají deskriptory popisující část přenosu zvuku. Je to dáno také tím, že specifikace USB audio [3] nepopisuje pouze přenos audia po USB. Nabízí také prostředky pro

popis topologie vstupů, výstupů, různých efektových jednotek přepínačů, směšovačů a podobně včetně jejich ovládání. Bylo by například možné takto realizovat kompletní ovládání mixážního, kde by přes USB mohlo být realizováno pouze několik vstupů a výstupů a nebo i žádný. pultu Topologie modulu rádia z pohledu této specifikace je nejjednodušší možná. Je zde pouze jeden výstupní terminál přenosu zvuku přes USB, který má jako vstup nastaven vstupní terminál přijímač rádia.

31

Název pole | Délka | Hodnota
bLength | 1B | 9 | Délka deskriptoru.
bDescriptorType | 1B | 0x04 | Typ deskriptoru.
bInterfaceNumber | 1B | 0 | Pořadové číslo rozhraní.
bAlternateSetting | 1B | 0 | Identifikátor alternativní nastavení.
bNumEndpoints | 1B | 0 | Počet koncových bodů v tomto rozhraní.
bInterfaceClass | 1B | 1 | Třída rozhraní. (Audio)
bInterfaceSubClass | 1B | 1 | Podtřída rozhraní. (Control device)
bInterfaceProtocol | 1B | 0 | Vždy 0.
iInterface | 1B | 0 | Index na textový řetězec.

Tabulka 18: Deskriptor řídícího rozhraní zvuku.

Název pole | Délka | Hodnota
bLength | 1B | 9 | Délka deskriptoru.
bDescriptorType | 1B | 0x24 | Typ deskriptoru.
bDescriptorSubType | 1B | 0x01 | Podtyp deskriptoru. (Hlavička)
bcdADC | 2B | 0x0100 | Verze USB Audio specifikace.
wTotalLength | 2B | 30 | Celková délka deskriptorů tohoto rozhraní.
bInCollection | 1B | 1 | Počet rozhraní pro odesílání zvuku.
baInterfaceNr(1) | 1B | 1 | Index rozhraní pro odesílání zvuku.

Tabulka 19: Deskriptor řídícího rozhraní zvuku - hlavička.

32

Název pole | Délka | Hodnota
bLength | 1B | 12 | Délka deskriptoru.
bDescriptorType | 1B | 0x24 | Typ deskriptoru.
bDescriptorSubType | 1B | 0x02 | Podtyp deskriptoru. (Vstupní terminál)
bterminalID | 1B | 1 | Identifikátor terminálu.
wTerminalType | 2B | 0x0710 | Typ terminálu. (Přijímač rádia)
bAssocTerminal | 1B | 0 | Přidružený terminál. (Nejedná se o zvukové propojení)
bNrChannels | 1B | 2 | Počet zvukových kanálů.
wChannelConfig | 2B | 0x0003 | Bitová mapa konfigurace kanálů.
iChannelNames | 1B | 0 | Index na textový řetězec s názvem kanálů.
iTerminal | 1B | 0 | Index na textový řetězec s popisem terminálu.

Tabulka 20: Deskriptor řídícího rozhraní zvuku - vstupní terminál.

Název pole | Délka | Hodnota
bLength | 1B | 9 | Délka deskriptoru.
bDescriptorType | 1B | 0x24 | Typ deskriptoru.
bDescriptorSubType | 1B | 0x03 | Podtyp deskriptoru. (Výstupní terminál)
bterminalID | 1B | 2 | Identifikátor terminálu.
wTerminalType | 2B | 0x0101 | Typ terminálu. (Odesílání přes USB)
bAssocTerminal | 1B | 0 | Přidružený terminál. (Nejedná se o zvukové propojení)
bSourceID | 1B | 1 | Identifikátor připojeného vstupního terminálu.
iTerminal | 1B | 0 | Index na textový řetězec s popisem terminálu.

Tabulka 21: Deskriptor řídícího rozhraní zvuku - výstupní terminál.

Řízení probíhá přes řídící rozhraní zvuku (Audio control interface), které je vždy napojeno

na koncový bod 0. V popisu tohoto rozhraní se skrývá i topologie. Skládá se z deskriptorů v tabulkách 18, 19, 20 a 21.
První deskriptor pouze určuje, že bude následovat popis rozhraní řízení zvuku třídy audio. Následující deskriptor (tabulka 19) tvoří hlavičku třídně specifického popisu rozhraní. Speci-

fikuje jednak použitou verzi USB Audio specifikace a také seznam rozhraní pro odesílání zvuku přes USB. Počet položek v tomto seznamu určuje hodnota pole bInCollection. Poté se na konec deskriptoru pro každé rozhraní přidá jedna položka. V tomto případě je použito pouze jediné rozhraní.
Zbylá dvojice deskriptorů (tabulka 20 a 21) popisuje vlastní topologii. Výstupní terminály

mají vždy pole bSourceID, které se nastaví na hodnotu bTerminalType vstupního terminálu, se kterým je propojen.
Dále následuje sada deskriptorů popisující rozhraní pro odesílání zvuku (audio streaming interface). Stejně jako řídící rozhraní zde se začíná standardním deskriptorem rozhraní, který

nese základní informace o rozhraní.

33

Název pole | Délka | Hodnota
bLength | 1B | 9 | Délka deskriptoru.
bDescriptorType | 1B | 0x04 | Typ deskriptoru.
bInterfaceNumber | 1B | 1 | Pořadové číslo rozhraní.
bAlternateSetting | 1B | 0 | Identifikátor alternativní nastavení.
bNumEndpoints | 1B | 0 | Počet koncových bodů v tomto rozhraní.
bInterfaceClass | 1B | 1 | Třída rozhraní. (Audio)
bInterfaceSubClass | 1B | 2 | Podtřída rozhraní. (Streaming)
bInterfaceProtocol | 1B | 0 | Vždy 0.
iInterface | 1B | 0 | Index na textový řetězec.

Tabulka 22: Deskriptor rozhraní odesílání zvuku.

Název pole | Délka | Hodnota
bLength | 1B | 9 | Délka deskriptoru.
bDescriptorType | 1B | 0x04 | Typ deskriptoru.
bInterfaceNumber | 1B | 1 | Pořadové číslo rozhraní.
bAlternateSetting | 1B | 1 | Identifikátor alternativní nastavení.
bNumEndpoints | 1B | 1 | Počet koncových bodů v tomto rozhraní.
bInterfaceClass | 1B | 1 | Třída rozhraní. (Audio)
bInterfaceSubClass | 1B | 2 | Podtřída rozhraní. (Streaming)
bInterfaceProtocol | 1B | 0 | Vždy 0.
iInterface | 1B | 0 | Index na textový řetězec.

Tabulka 23: Deskriptor rozhraní odesílání zvuku.

V tomto případě jsou použity hned dva deskriptory (tabulka 22 a 23). Liší se pouze ve dvou

polích a to bAlternateSetting a bNumEndpoints. Druhé z těchto polí určuje počet koncových bodů použitých v rozhraní. Díky tomu, že je v prvním deskriptoru tento počet nulový, má hostitel možnost zvolit toto alternativní nastavení vždy, když nemá zájem o zvuková data. K identifikaci tohoto nastavení slouží hodnota v prvním ze zmíněných polí bAlternateSettings.

Název pole | Délka | Hodnota
bLength | 1B | 7 | Délka deskriptoru.
bDescriptorType | 1B | 0x24 | Typ deskriptoru.
bDescriptorSubType | 1B | 1 | Podtyp deskriptoru.
bTerminalLink | 1B | 2 | Index výstupního terminálu.
bDelay | 1B | 1 | Zpoždění v paketech.
wFormatTag | 2B | 1 | Formát přenášených dat. (PCM)

Tabulka 24: Deskriptor formátu zvuku - hlavička.

34

Název pole | Délka | Hodnota
bLength | 1B | 11 | Délka deskriptoru.
bDescriptorType | 1B | 0x24 | Typ deskriptoru.
bDescriptorSubType | 1B | 2 | Podtyp deskriptoru.
bFormatType | 1B | 1 | Typ formátu.
bNrChannels | 1B | 2 | Počet kanálů.
bSubFrameSize | 1B | 2 | Velikost jednoho podrámce v bytech.
bSubFrameResolution | 1B | 16 | Počet platných bitů jednoho podrámce.
bSamFreqType | 1B | 1 | Způsob určení vzorkovací frekvence. (Diskrétní)
tSamFreq(1) | 3B | 48000 | Vzorkovací frekvence v Hz.

Tabulka 25: Deskriptor formátu zvuku.

V tabulce 24 a 25 jsou deskriptory popisující formátování a způsob přenosu zvukových dat. Formátování dat je specifikováno v [4]. Podle tohoto dokumentu se proud zvukových dat dělí do paketů, které se odesílají každou 1 ms. Paket je složen z rámců (frames), které reprezentují úrovně

všech kanálů zachycených v jeden okamžik. Samotné úrovně jednotlivých kanálů se nazývají podrámce (subframes).

Deskriptor třídně specifické hlavičky v tabulce 24 nese kromě polí pro identifikaci sebe sama pouze tři zajímavá pole.
První je bTerminalLink. Identifikuje, ke kterému výstupnímu terminálu se popis formátu vztahuje.
Pole bDelay je hodnota prodlevy mezi zachycením vzorku a jeho odesláním. Veličinou je počet paketů. Hodnota tohoto pole má význam pouze v případe simultánního záznamu zvuku z více zvukových karet a podobně. V případě přijímače rádia na ní nezáleží.
Posledním polem je wFormatTag, které určuje, že hodnoty jednotlivých vzorků budou ve formátu PCM jako čísla se znaménkem. I zde nabízí USB Audio specifikace značnou volnost a kromě formátu PCM je možné přenášet zvuk komprimovaný různými kodeky. Detailnější specifikace je v [4].

Následující deskriptor, vyobrazený v tabulce 25, blíže specifikuje parametry PCM formátu. Toto specifikuje hodnota pole bFormatType.
Jak název napovídá, pole bNrChannels určuje počet kanálů. Pole bSubframeSize obsahuje velikost jednoho podrámce (vzorku) v Bytech. Zároveň pole bSubFrameResolution nese počet

platných bitů v podrámci.
Konec deskriptoru je věnován specifikaci vzorkovacích frekvencí. Pomocí hodnoty v poli bSamFreqType se určí způsob specifikace frekvencí. V případě modulu je použita pouze jediná diskrétní frekvence, která je specifikována v poli tSamFreq(1). Je možné zde specifikovat více

diskrétních frekvencí, ze kterých si poté hostitel vybírá, a nebo specifikovat interval.
V tabulce 26 je deskriptor koncového bodu popisující koncový bod odesílání zvuku (audio streaming endpoint). Prvním zajímavým polem je adresa koncového bodu v poli bEndpointAdd-

35

Název pole | Délka | Hodnota
bLength | 1B | 7 | Délka deskriptoru.
bDescriptorType | 1B | 0x25 | Typ deskriptoru.
bEndpointAddress | 1B | 0x81 | Číslo koncového bodu.
bmAttributes | 1B | 0b00000001 | Bitová mapa s atributy.
wMaxPacketSize | 2B | 384 | Maximální velikost paketu v bytech.
bInterval | 1B | 1 | Interval Odesílání.
bRefresh | 1B | 0 | Frekvence synchronizace. (Nepoužito)
bSynchAddress | 1B | 0 | Adresa synchronizačního koncového bodu. (Nepoužito)

Tabulka 26: Deskriptor koncového bodu odesílání zvuku.

ress. Jako adresa je použito číslo koncového bodu s tím, že v případě vstupního koncového bodu (směr do hostitele) se sedmý (nejvyšší) bit nastaví na 1. U opačného směru tento bit zůstává

nulový.
Pole bmAttributes obsahuje bitovou mapu atributů koncového bodu. Význam bitů 0 a 1 je

následující:

- 00 - Řídící koncový bod.
- 01 - Izochronní koncový bod.
- 10 - Hromadný koncový bod.
- 11 - Koncový bod přerušení.

Zbylé bity popisují způsob synchronizace izochronních koncových bodů, která ale není použita. Jejich popis je v kapitole 5.12.4 USB specifikace [2].

Pole wMaxPacketsize určuje největší možnou velikost paketu. V tomto případě se spočítá z deskriptoru v tabulce 25 jako bNrChannels · bSubF rameSize ·

tSamF req(1)
1000 Vypočtenou hodnotu
je nutné vždy zaokrouhlit nahoru. Například v případě vzorkovací frekvence 44,1 kHz bude ve většině paketů 44 rámců, ale každý desátý jich bude mít 45.
Pole bInterval určuje periodu čtení dat z koncového bodu. Hodnota 1 znamená, že se bude hostitel pokoušet číst data z koncového bodu každou 1 ms. Zbývající dvě pole se vztahují k synchronizaci, která nebyla použita a tudíž jsou nastavena na hodnotu 0.
Posledním deskriptorem popisujícím přenos zvuku je třídně specifický deskriptor koncového bodu v tabulce 27. Za běžnými uvozujícími poli se nachází bitová mapa s atributy bmAttributes. Význam bitů je následující:
- Bit 0 - Koncový bod podporuje žádost o počáteční nastavení vzorkovací frekvence.
- Bit 1 - Koncový bod podporuje dynamickou změnu vzorkovací frekvence za běhu.

36

Název pole | Délka | Hodnota
bLength | 1B | 9 | Délka deskriptoru.
bDescriptorType | 1B | 0x05 | Typ deskriptoru.
bDescriptorSubType | 1B | 1 | Podtyp deskriptoru.
bmAttributes | 1B | 0b00000000 | Bitová mapa s atributy.
bLockDelayUnits | 1B | 0 | Jednotky prodlevy stabilizace synchronizace. (Nepoužito).
wLockDelay | 2B | 0 | Doba prodlevy stabilizace synchronizace. (Nepoužito)

Tabulka 27: Deskriptor koncového bodu odesílání zvuku specifický pro danou třídu.

- Bit 2-6 - Vyhrazeno - musí být nulové.
- Bit 7 - Pokud je nastaveno musí se přenášená data vždy doplnit nulami tak, aby měl každý

paket velikost wMaxPacketSize.

Dvě pole na konci deskriptoru umožňují specifikovat dobu potřebnou pro stabilizaci synchronizace. Synchronizace koncového bodu není použita, takže obě hodnoty jsou nulové.

37

### 4.1.9 Deskriptory konfigurace vztažené k USB I²C tunelu

Název pole | Délka | Hodnota
bLength | 1B | 9 | Délka deskriptoru.
bDescriptorType | 1B | 0x04 | Typ deskriptoru.
bInterfaceNumber | 1B | 2 | Číslo rozhraní.
bAlternateSettngs | 1B | 0 | Identifikátor alternativního nastavení.
bNumEndpoints | 1B | 2 | Počet koncových bodů v tomto rozhraní.
bInterfaceClass | 1B | 255 | Třída rozhraní (Vendor specific).
bInterfaceSubClass | 1B | 0 | Podtřída rozhraní.
bInterfaceProtocol | 1B | 255 | Protokol rozhraní (Vendor specific).
iInterface | 1B | 0 | Index řetězce s popisem rozhraní (Nepoužit).

Tabulka 28: Deskriptor rozhraní USB - I²C tunelu.

Deskriptor ozhraní USB - I²C tunelu v tabulce 28 je podobný jako zvuková rozhraní. Liší se

samozřejmě třídou zařízení, kde třída 255 určuje, že se nejedná o žádné ze standardizovaných rozhraní, ale je definováno výrobcem. Stejný význam má protokol číslo 255.

Název pole | Délka | Hodnota
bLength | 1B | 9 | Délka deskriptoru.
bDescriptorType | 1B | 0x05 | Typ deskriptoru.
bEndpointAddress | 1B | 0x82 / 0x02 | Číslo koncového bodu.
bmAttributes | 1B | 0b00000010 | Bitová mapa s atributy.
wMaxPacketSize | 2B | 32 | Maximální velikost paketu v bytech.
bInterval | 1B | 0 | Interval Odesílání. (Nemá význam)
bRefresh | 1B | 0 | Frekvence synchronizace. (Nemá význam)
bSynchAddress | 1B | 0 | Adresa synchronizačního koncového bodu. (Nemá význam)

Tabulka 29: Deskriptor koncových bodů USB - I²C tunelu.

V tabulce 29 jsou oba deskriptory koncových bodů pro USB I²C tunel. Liší se pouze v adrese.

Pole bmAttributes obsahuje pouze informaci o tom, že se jedná o koncový bod hromadného přenosu dat (bulk endpoint). Poslední tři pole mají v případě tohoto druhu koncového bodu

vždy hodnotu 0.
Maximální velikost paketu wMaxPacketSize může být 8, 16, 32 nebo 64 B (viz. [2] kap. 5.8.3). Vzhledem k velikosti nejdelšího možného příkazu a odpovědi odesílaného přes I²C , jsem zvolil

velikost 32 B.

38

### 4.2 Microchip Harmony framework

Harmony framework obsahuje mimo jiné také ovladače pro USB včetně USB Audio 1.0. Součástí je i vzorový projekt pro USB reproduktor, ze kterého jsem původně vycházel.
Poté co jsem projekt upravil tak, aby zvuková data nepřijímal, ale odesílal, se začal MCU

restartovat. Z fóra firmy Microchip ( http://www.microchip.com/forums/FindPost/827487)

jsem zjistil, že jde o již nahlášený problém chybné inicializace, v důsledku které dochází k dělení nulou a k resetu MCU. Na fóru je také uveřejněno, jak tuto chybu opravit.
Opravením této chyby jsem se dostal k odesílání zvuku. I když modul správně prošel enumerací a konfigurací, do hostitele se přenášelo pouze ticho. Pomocí USB analyzátoru jsem zjistil, že modul od hostitele dostává IN tokeny, ale posílá pouze pakety nulové délky, jako by neměl žádná data k odeslání.
Rozhodl jsem se implementovat ovladač USB Audia jako vendor endpoint (koncový bod specifikovaný výrobcem). Pro potřeby modulu stačí pouze zajistit odesílání zvuku přes izochronní

koncový bod a reagovat na požadavek změny alternativního nastavení funkce povolením nebo zakázáním izochronního koncového bodu. Došel jsem ke zcela totožnému chování modulu jako s původním ovladačem.
Upravil jsem tedy vlastní ovladač tak, aby izochronní koncový bod byl povolen neustále. Po této úpravě se začal přenášet zvuk, ale implementace vendor endpointu je pravděpodobně příliš pomalá, takže přibližně každý druhý paket byl následován paketem nulové délky.

### 4.3 Vlastní implementace USB

Kvůli zmiňovaným problémům s Harmony frameworkem, které se mi nepodařilo vyřešit, jsem se rozhodl napsat ovladač v MCU sám. Ke zprovoznění USB modulu je potřeba, aby MCU podporoval pouze několik požadavků hostitele a implementovat jednoduchý stavový stroj.

### 4.3.1 USB modul v MCU

Dokumentace USB v MCU se nachází v obecném manuálu [12] pro celou řadu těchto 32 bitových MCU. Detaily pro konkrétní typ jsou v manuálu [8]. Pravděpodobně díky existenci Harmony

frameworku je dokumentace relativně stručná.
USB modul v MCU PIC32MX je velmi podobný USB modulu v 8 bitovém MCU PIC16F1454, na kterém jsem se snažil původně modul tuneru postavit.
Prvním překvapením pro mne bylo, že podle USB specifikace nesmí být na sběrnici přivedeno žádné napětí, pokud není sběrnice napájena z hostitele. U zařízení napájených z USB sběrnice toto není třeba řešit. MCU PIC32 má vyhrazený vstup VBUS právě pro snímání napětí na USB sběrnici. I když je ho možné pomocí konfiguračních slov deaktivovat, je nutné jej použít. Pokud na tento vstup není přivedeno napětí, USB modul v MCU nepracuje.
Vlastní konfigurace USB modulu je v případě USB zařízení v celku jednoduchá. Bitem USBPWR v registru U1PWRC se provede spuštění USB modulu.

39

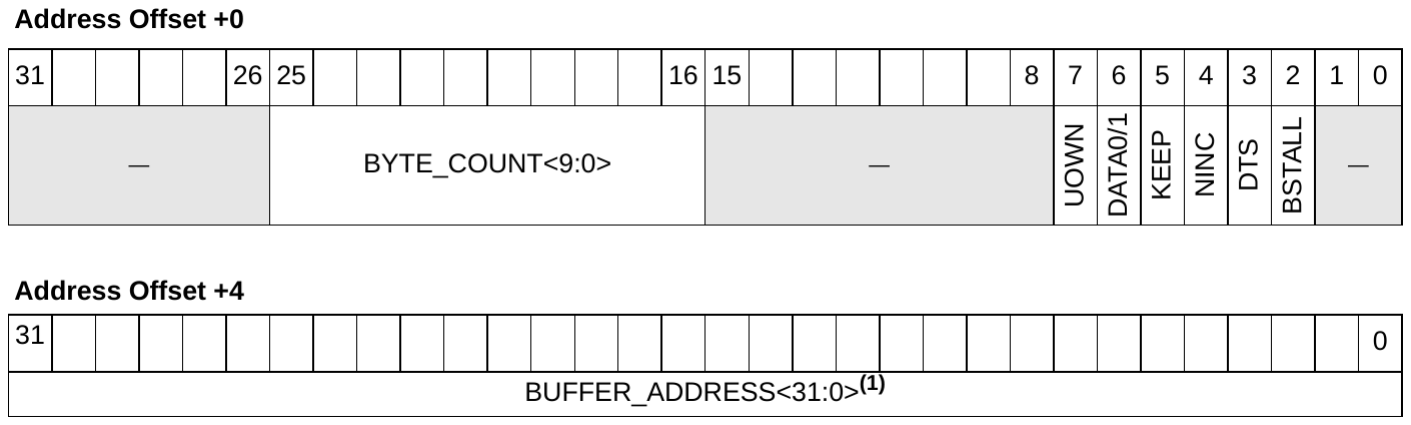
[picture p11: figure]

Obrázek 7: Formát deskriptoru USB bufferu předaného do USB modulu. (Převzato z [12].)

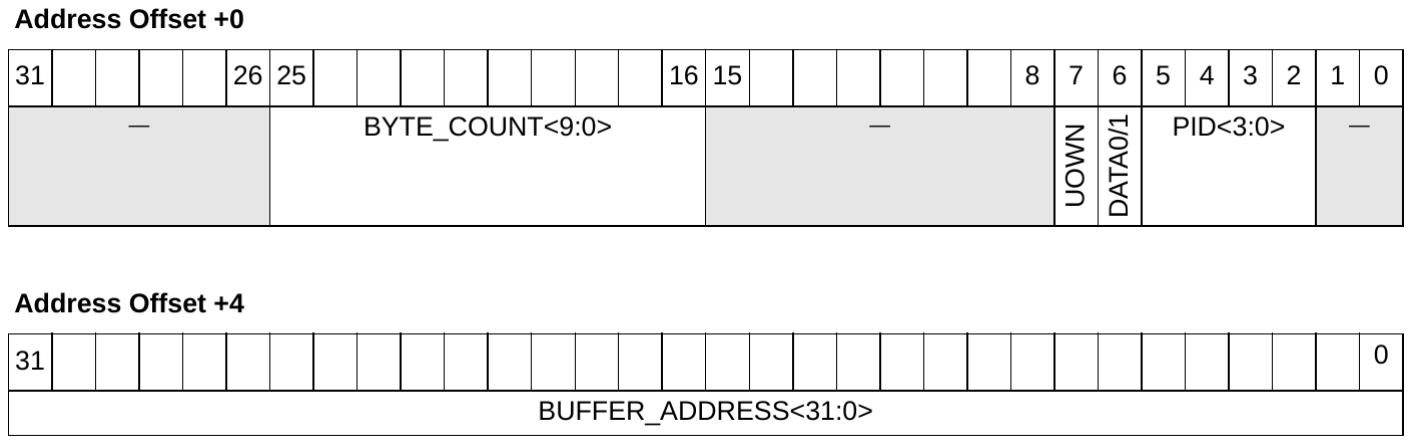
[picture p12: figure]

Obrázek 8: Formát deskriptoru USB bufferu předaného do aplikace. (Převzato z [12].)

Dále je potřeba do registrů U1BDTP1-3 nastavit dolní tři byty ukazatele na tabulku deskriptorů bufferů. Každému koncovému bodu, pro každý směr, jsou přiřazeny dva záznamy v této tabulce, lichý a sudý. Tvoří takto dvouprvkovou FIFO frontu. Každý záznam v této tabulce nese ukazatel na buffer pro příjem nebo odesílání dat a další nezbytné informace. Tabulka může být umístěna kdekoliv v zapisovatelné paměti MCU, ale její adresa musí být zarovnaná na 512 B. Jádro MCU používá rozdílné adresy pro přístup k datům z programu (virtuální adresy) a přístup k datům z hardwarových modulů (fyzické adresy). Adresu ukládanou do registrů U1BDTP Je

tudíž potřeba přeložit. To se provede logickým součinem s hodnotou 0x1FFFFFFF.
Dále je potřeba zinicializovat samotnou tabulku deskriptorů bufferů. Jak je patrné z obrázků 7 a 8, význam dat v jednotlivých záznamech tabulky je mírně odlišný v případě, že tabulku předáváme do USB modulu a v případě, že USB modul zpracoval token pro daný koncový bod a tabulku vrátil aplikaci. Význam jednotlivých polí je následující:
- BYTE_COUNT - Počet bytů k přijetí nebo odeslání.
- UOWN - Pokud je nastaven na 1, buffer patří USB modulu a nelze jej měnit. Po zpraco-

vání paketu bude tento bit nastaven USB modulem zpět na hodnotu 0.

- DATA0/1 - Určuje jestli se paket odešle s PID DATA0 nebo DATA1. V případě přijmu

určí jestli se očekává paket s PID DATA0 nebo DATA1.

- KEEP - Pokud je nastaven na 1, USB modul si tento buffer ponechá napořád.

40

- NINC - Pokud je nastaven na adresa DMA nebude inkrementována.
- DTS - Pokud je nastaven na 1, USB modul bude při přijmu ignorovat pakety, kde PID (DATA0/1) neodpovídá hodnotě pole DATA0/1. Pokud je nastaven na 0, tato kontrola

nebude prováděna.

- BSTALL - Pokud je nastaven na 1, byl přijat nebo bude vyslán STALL.
- PID - Druh přijatého tokenu.
- BUFFER_ADDRESS - Fyzická adresa na buffer s data k odeslání nebo přijmu.

Jak je patrné z předchozího výčtu je nezbytné inicializovat přinejmenším bit UOWN na hodnotu 0.
Po tomto kroku je možné spustit USB modul nastavením bitu USBEN v registru U1CON na 1.
Aplikace si musí udržovat informace o tom jestli má používat lichý nebo sudý buffer. USB

modul umožňuje resetovat všechny koncové body v obou směrech tak, aby znova začaly sudým bufferem, nastavením bitu PBRST v registru U1CON na 1.
Ještě je nutné nakonfigurovat používané koncové body v registrech U1EP0 - U1EP15. Nastavením bitů EPTXEN a nebo EPRXEN odesílání a nebo příjem, pokud se nejedná o koncový bod pro řídící přenosy, je dobré zakázat příjem SETUP tokenů nastavením bitu EPCONDIS. A

pokud se nejedná o koncový bod pro isochronní přenos dat povolit handshake nastavením bitu EPHSK.
Pro příjem a odesílání stačí nastavit příslušný záznam v tabulce deskriptorů bufferů s nastavením bitu UOWN jej předat do USB modulu. Po vyřízení přijmu nebo odesílání USB modul nastaví bit TRNIF v registru U1IR a současně nastaví v registru U1STAT tato pole:
- ENDPT - Číslo koncového bodu 0-15.
- DIR - Směr. Pokud má hodnotu 1 poslední transakce bylo odesílání (IN transakce), pokud 0 poslední transakce byla příjem (OUT transakce).
- PPBI - Pokud má hodnotu 1 byl vyřízen lichý buffer, pokud 0, byl vyřízen sudý buffer.
- 2 bity mezera.

Pakliže je hodnota tohoto registru posunuta o dva bity doprava, je ji možné přímo použít jako index v tabulce deskriptorů bufferů.
Při přijmu setup tokenu (zahájení řídící transakce) dojde k nastavení bitu PKTDIS regis-

tru U1CON. Dokud je tento bit nastaven je zastaveno zpracování všech tokenů. Po připravení odpovědi je nutné tento bit nastavit na hodnotu 0.
Aplikace by dále měla monitorovat v registru U1CON tyto bity: (Více v kapitole 4.3.3.)

41

- IDLEIF - Zařízení bylo suspendováno.
- URSTIF - Zařízení bylo resetováno.

### 4.3.2 Standardní USB požadavky

Název pole | Délka
bmRequestType | 1B | Bitová mapa s obecným popisem požadavku.
bRequest | 1B | Specifikace požadavku.
wValue | 1B | Obecná hodnota.
wIndex | 1B | Obecný index.
wLength | 1B | Velikost dat, které je nutné dále přijmou nebo odeslat.

Tabulka 30: Hlavička USB požadavků.

Standardní požadavky na zařízení jsou detailně popsány v [2] v kapitole 9.3. Implementoval

jsem pouze požadavky nutné k funkci modulu rádia.
Standardní požadavky odesílané z hostitele mají vždy stejnou hlavičku popsanou v tabulce 30. Význam polí wValue a wIndex je vždy specifický danému požadavku. Význam bitů pole bmRequestType je náledující:
- Bit 7: Směr případné datové části.

– 1 - Z hostitele do zařízení,

– 0 - Ze zařízení do hostitele.

- Bity 6-5: Typ požadavku.

– 0 - Standardní požadavek.

– 1 - Požadavek specifický pro danou třídu zařízení.

– 2 - Výrobcem specifikovaný požadavek.

– 3 - Vyhrazeno.

- Bity 4-0: Příjemce požadavku.

– 0 - Zařízení.

– 1 - Rozhraní.

– 2 - Koncový bod.

– 3 - Jiný.

– 4-31 - Vyhrazeno.

Byly implementovány následující požadavky: (V závorkách jsou uvedeny hodnoty bRequest)

42

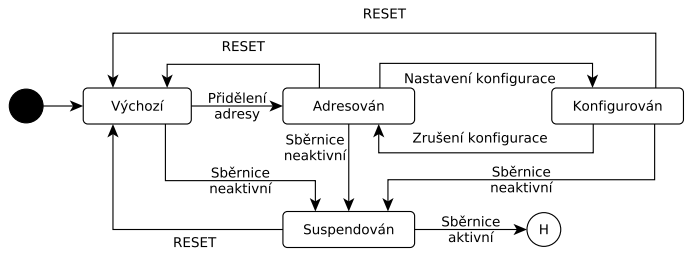
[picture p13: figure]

Obrázek 9: Zjednodušený diagram stavů USB zařízení.

- GET_STATUS (0): Odpovědí na tento požadavek jsou dva byty. Předposlední bit určuje, jestli se zařízení smí probudit, když je suspendováno (remote wakeup). Toto není

podporováno, bit je vždy nula. Poslední nejnižší bit určuje, jestli má zařízení vlastní napájení. Tento bit je taktéž vždy nula. Ostatní bity jsou rezervovány a jsou vždy nulové.

- SET_ADDRESS (5): V poli wValue zařízení obdrží novou adresu.
- GET_DESCRIPTOR (7): Hostitel žádá o deskriptor. V horním byte wValue je typ

deskriptoru, v dolním byte index deskriptoru. wIndex je buď nula nebo specifikuje ID jazyka. wLength určuje maximální délku odpovědi. Hostitel může požadovat pouze začátek deskriptoru.

- GET_CONFIGURATION (8): Hostitel žádá o index aktuálně používané konfigurace.

Ta je odeslána jako jeden byte.

- SET_ADDRESS (5): V poli wValue zařízení obdrží index nové konfigurace.
- SET_INTERFACE (11): V poli wValue zařízení obdrží index nového alternativní nastavení pro rozhraní s indexem v poli wIndex. (Implementováno v ovladači USB audio.)

### 4.3.3 Stavy USB zařízení

Na obrázku 9 je stavový diagram USB zařízení. Diagram je zjednodušen pouze na stavy důležité pro modul.

- Výchozí: Stav po zapnutí a inicilizaci zařízení. Při vstupu do tohoto stavu se nastaví

adresa zařízení na výchozí hodnotu 0.

- Adresován: Do tohoto stavu se přejde po zpracování požadavku nastavení adresy. Veškerá

další komunikace bude probíhat na této adrese. Ovšem adresu do registru MCU U1ADDR

je nutné nastavit až po dokončení transakce - odeslání paketu nulové délky.

- Konfigurován: Do tohoto stavu se přejde na základě požadavku nastavení konfigurace.

43

- Suspendován: K suspendování zařízení může dojít obecně kdykoliv. Do tohoto stavu se

přejde pokud na sběrnici není zaznamenána aktivita po dobu 3 ms. Toto detekuje hardware MCU. V tomto stavu musí zařízení snížit svoji spotřebu na nejvýše 0,5 mA.

Dále je potřeba počítat s faktem, že zařízení může být kdykoliv resetováno a vrátí se tak do výchozího stavu, není stanoveno pořadí, v jakém budou žádosti přicházet a kterákoli transakce může být předčasně ukončena vysláním dalšího setup tokenu.

### 4.4 USB I²C tunel

USB - I²C tunelu je zjednodušen tak, aby vyhovoval potřebám ovládání tunerů. Není obecně použitelný pro jakoukoliv I²C komunikaci. Umožňuje pouze odeslání jedné ze čtyř pevně speci-

fikovaných adres, následované čtením nebo zápisem až 16-ti bytů.

Název pole | Délka
id | 1 B | Identifikátor požadavku.
tuner | 1 B | Číslo tuneru.
type | 1 B | Typ požadavku.
rw_size | 1 B | Velikost pole cmd v bytech.
cmd | 0 - 16 B | Případná data odesílána po I²C vyjma adresy.

Tabulka 31: Formát požadavku USB - I²C tunelu.

Tabulka 31 popisuje formát požadavku pro čtení nebo zápis dat na I²C sběrnici. Význam

polí je následující:

- id - Hodnota 0-255, kterou je možné použít pro přiřazení odpovědi k požadavku.
- tuner - Výběr tuneru na modulu rádia. 0 pro hlavní tuner A, ze kterého je přenášen zvuk,

1 pro tuner B.

- type - Typ požadavku. 0 Pro zápis na I²C sběrnice, 1 pro čtení z I²C sběrnice, 2 pro ping
- modul v odpovědi pouze vrátí přijatá data.
- rw_size - V případě zápisu velikost pole cmd v bytech, v případě čtení počet bytů, které

budou přečteny. Hodnota 0 - 16.

- cmd - V případě zápisu data vysílaná na I²C sběrnici.
- id - Hodnota 0-255, kterou je možné použít pro přiřazení odpovědi k požadavku.
- error - Vyjadřuje, jestli při vyřizování požadavku došlo k chybě či nikoliv.

– 0 - Nedošlo k chybě.

44

Název pole | Délka
id | 1 B | Identifikátor požadavku.
error | 1 B | Číslo tuneru.
reply | 0 - 16 B | Případná odpověď tuneru z I²C sběrnice.

Tabulka 32: Formát odpovědi USB - I²C tunelu.

– 1 - I²C sběrnice je zaneprázdněna, probíhá komunikace.

– 2 - Nevalidní požadavek, neplatné číslo tuneru nebo příliš velké množství dat.

– 3 - Tuner není spuštěn a inicializován.

– 4 - Předchozí požadavek ještě nebyl vyřízen.

– 5 - Neplatný typ požadavku.

– 128 - Obecná chyba.

- reply - V případě úspěšného požadavku čtení, odpověď tuneru.

Komunikace z hostitele se provádí pomocí požadavků a odpovědí popsaných v tabulkách 31 a 32. Výjimkou je požadavek s typem 2 (ping), kdy modul rádia odešle zpět stejná data, která přijal. K práci s USB - I²C tunelem bych chtěl podotknout, že není možné odeslat další požadavek

před vyřízením předchozího. Po spuštění modulu rádia dochází k počáteční inicializaci tunerů. Podobu inicializace modul odpovídá chybovým kódem 3.
Vlastní modul I²C v MCU je dobře zdokumentován, jednak obecně pro celou rodinu MCU

v [10], detaily specifické pro mnou použitý typ MCU jsou potom v [8].
Je zbytečné popisovat zde konfiguraci I²C modulu. Chtěl bych ale upozornit na dvě hardwa-

rové chyby, které se modulu týkají. Obě jsou popsané v [13].

Při spuštěném modulu I2C1 nelze používat vývody RA0 a RA1, stejně tak při spuštěném modulu I2C2 nelze používat vývody RB5 a RB6. Druhou chybou je možnost dvojitého zápisu v případě, že během zápisu došlo k přerušení. Toto chování ve většině případů není problém. V případě I²C modulu se se zápisem spouští jednotlivé akce, takže může dojít například k dvojímu zápisu bytu na sběrnici. Řešením je před zápisem do registrů náchylných na tuto chybu zakázat

přerušení.
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

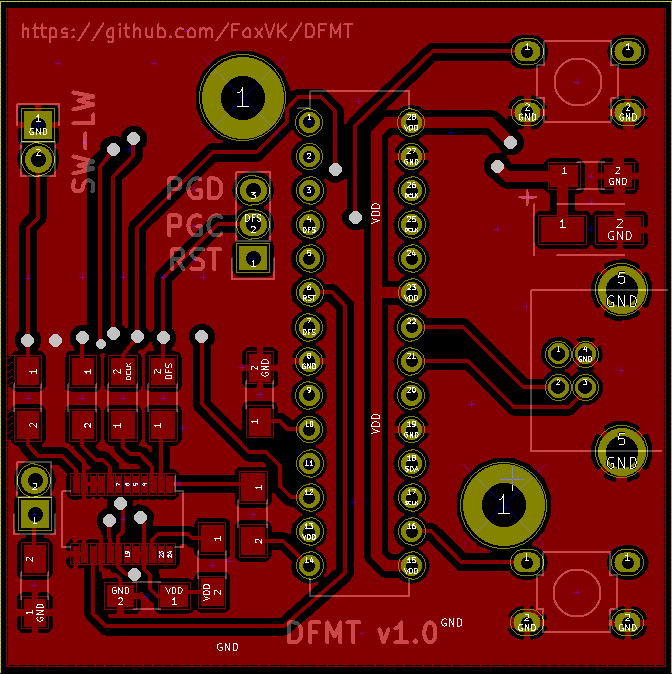
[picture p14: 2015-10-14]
hardware/exports/board-screenshot-t.png

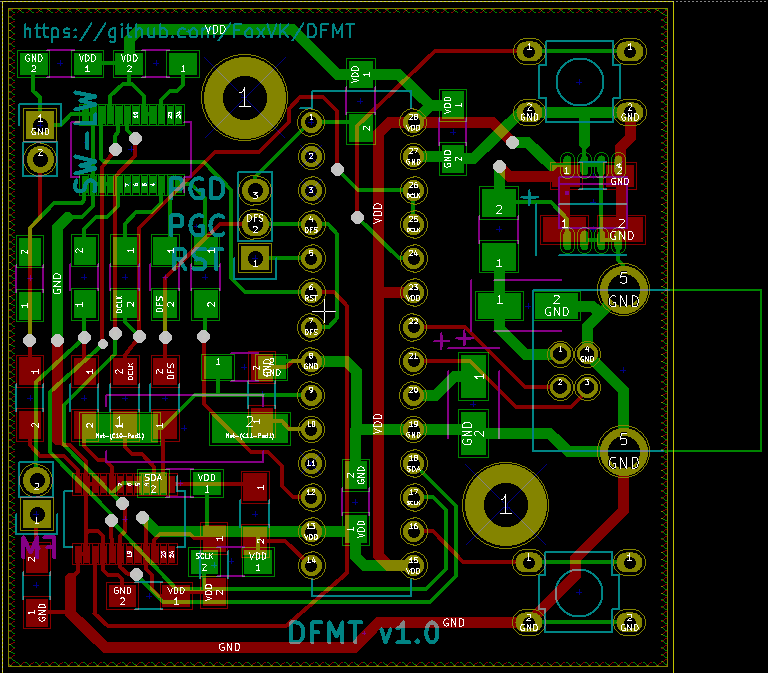
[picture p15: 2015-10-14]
hardware/exports/board-screenshot.png

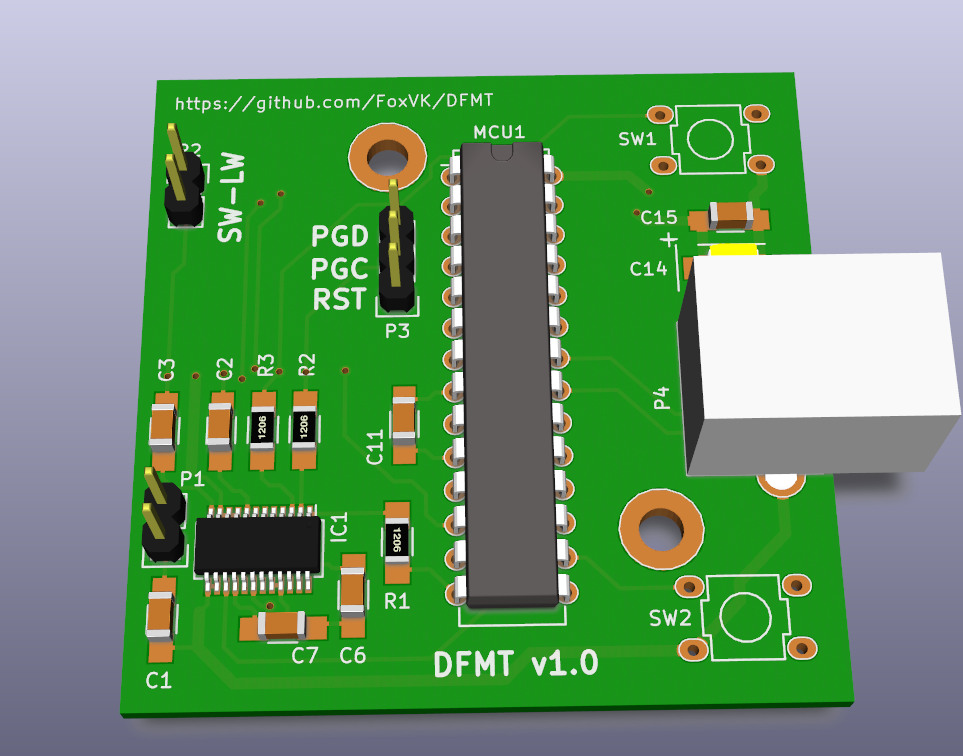
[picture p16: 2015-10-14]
hardware/exports/dfmt-top.png

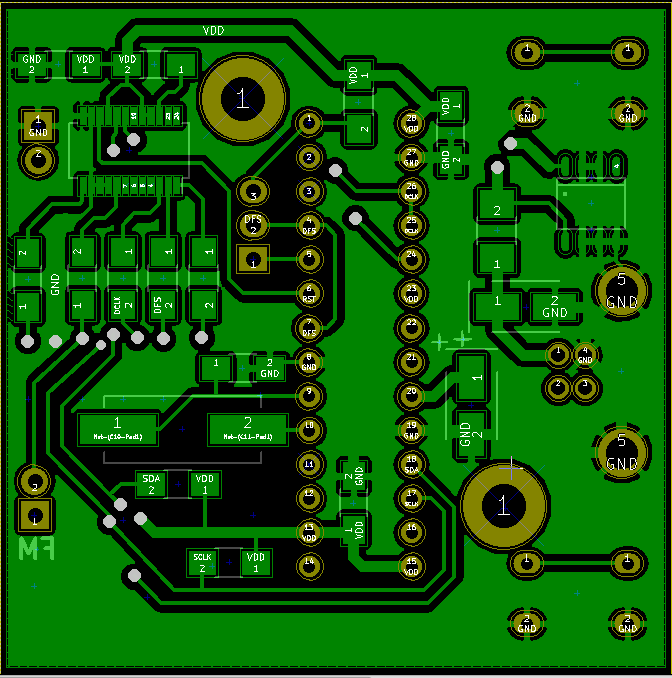
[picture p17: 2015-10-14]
hardware/exports/board-screenshot-b.png

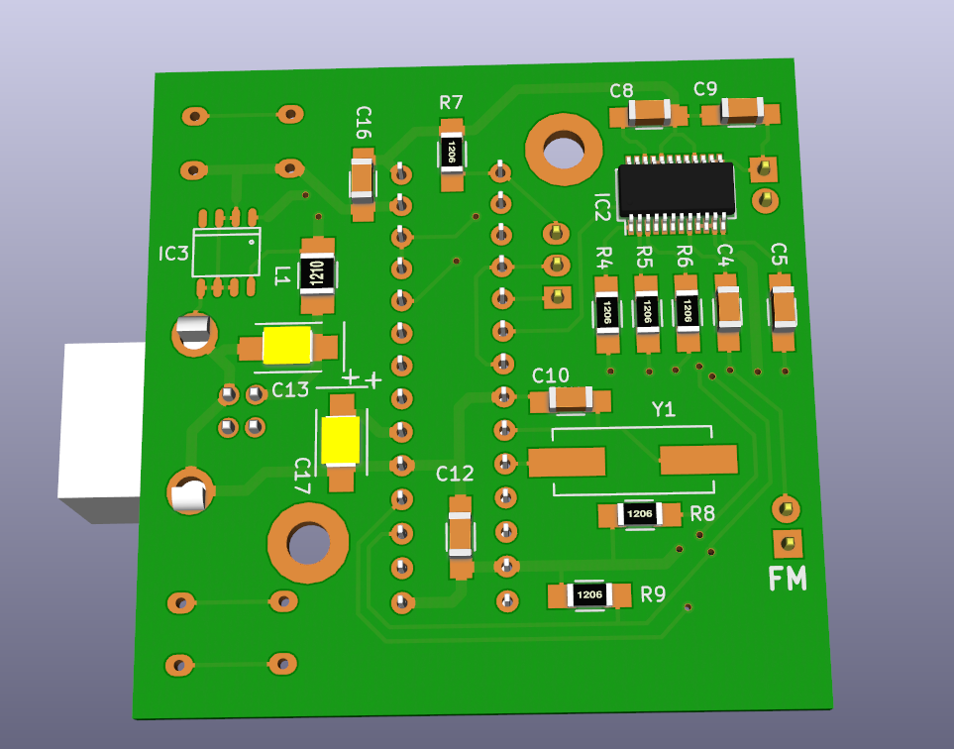
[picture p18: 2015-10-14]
hardware/exports/dfmt-botom.png

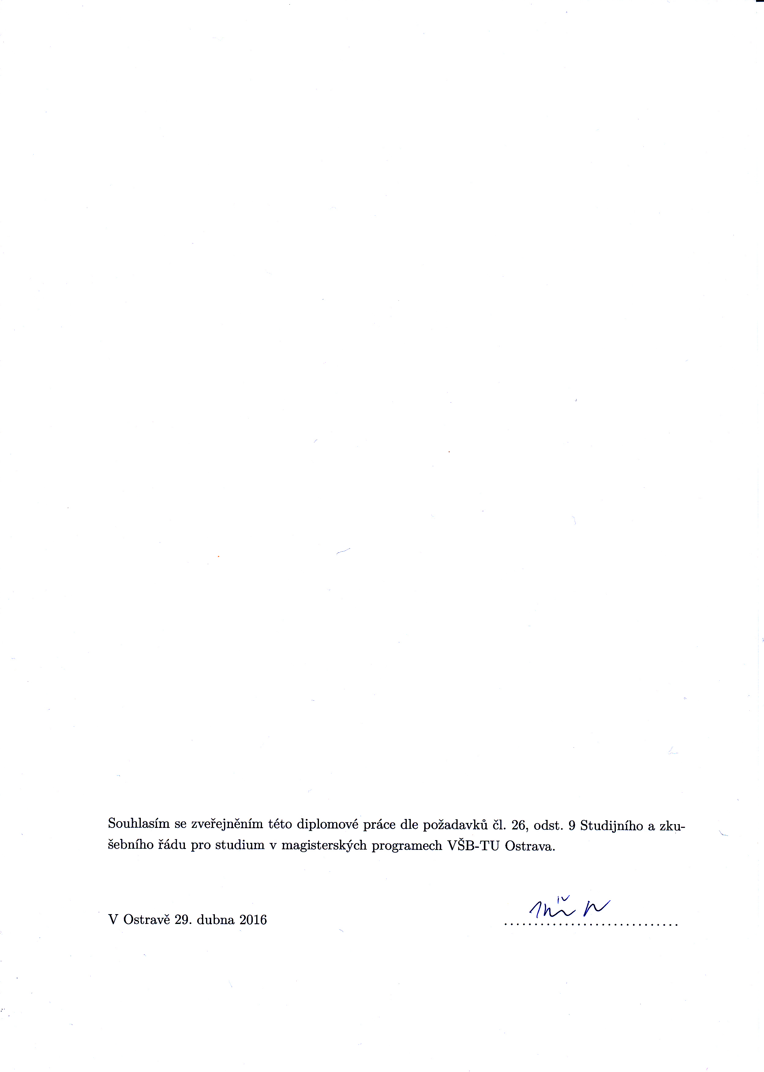
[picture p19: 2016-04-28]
diploma/figures/souhlas.jpg

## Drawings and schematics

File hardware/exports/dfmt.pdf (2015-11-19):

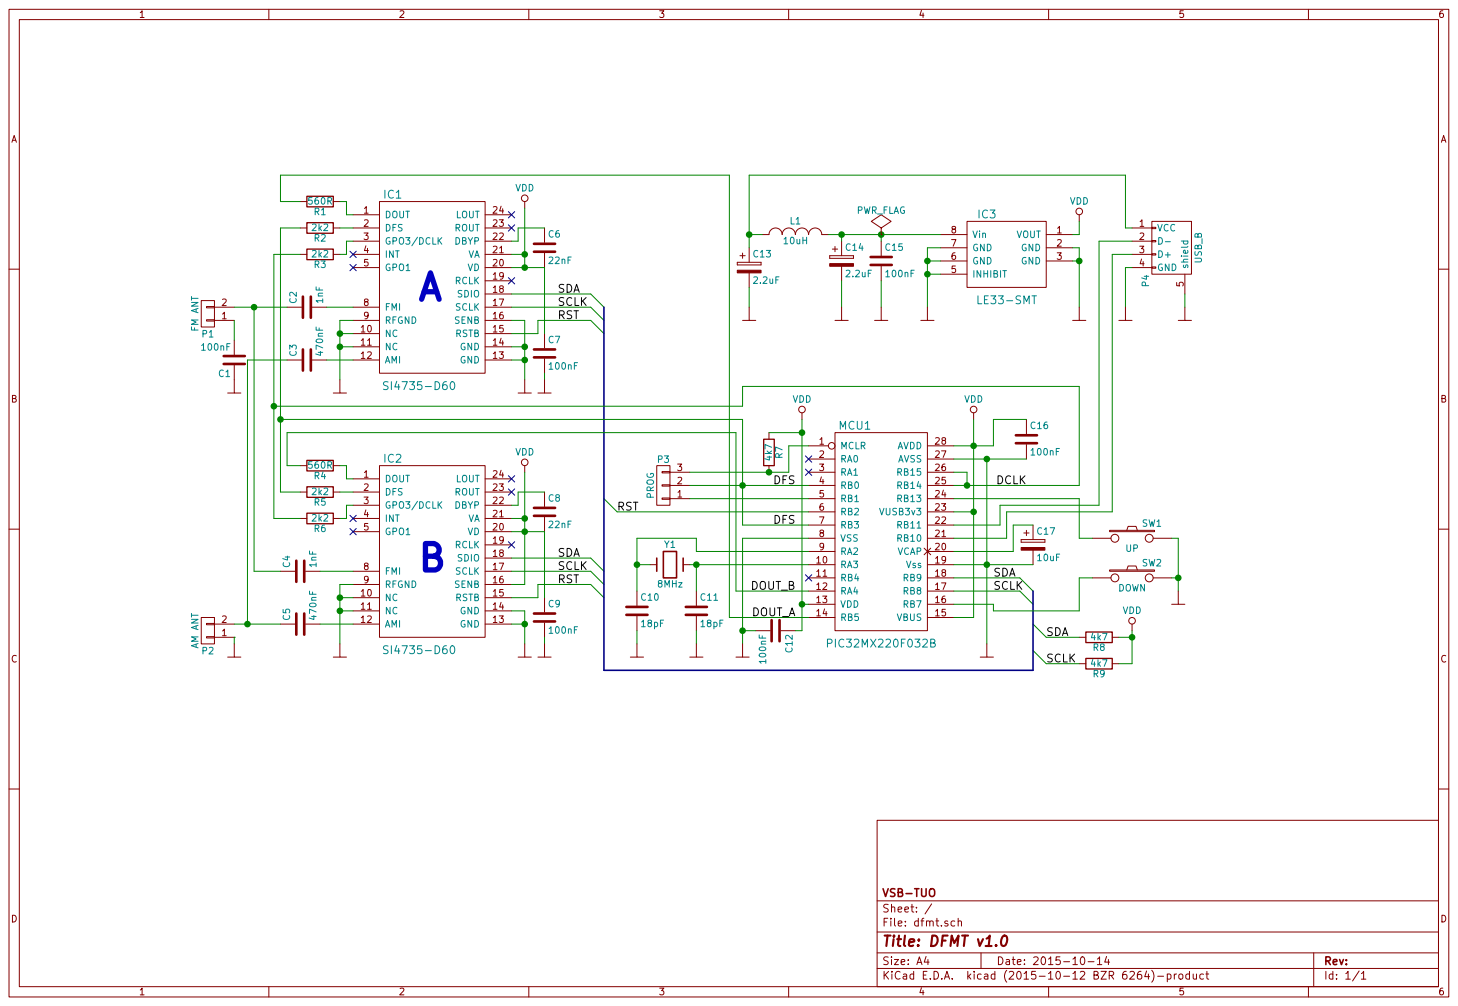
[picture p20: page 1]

SCLK | SW2 DOWN DOUT_A
DOUT_B

SDA

File: dfmt.sch Sheet: / VSB-TUO

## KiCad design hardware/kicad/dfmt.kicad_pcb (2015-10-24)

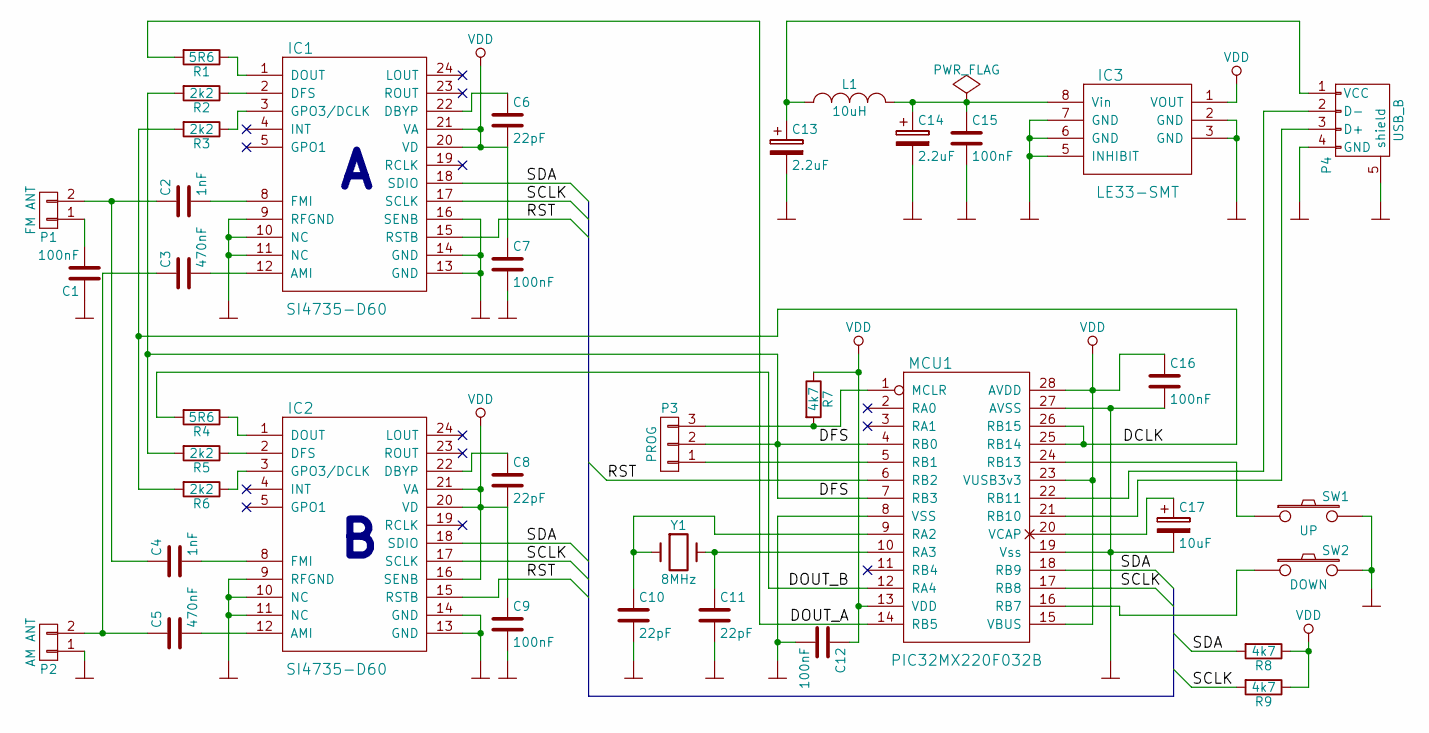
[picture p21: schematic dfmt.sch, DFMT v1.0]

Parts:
C1, C7, C9, C12, C15, C16: 100nF; C_1206_HandSoldering
C2, C4: 1nF; C_1206_HandSoldering
C3, C5: 470nF; C_1206_HandSoldering
C6, C8, C10, C11: 22pF; C_1206_HandSoldering
C13, C14: 2.2uF; TantalC_SizeB_EIA-3528_HandSoldering
C17: 10uF; TantalC_SizeB_EIA-3528_HandSoldering
IC1, IC2: SI4735-D60; SSOP-24_3.9x8.7mm_Pitch0.635mm
IC3: LE33-SMT; SO-8
L1: 10uH; R_1210_HandSoldering
MCU1: PIC32MX220F032B; DIP-28_W7.62mm
P1: FM ANT; Pin_Header_Straight_1x02
P2: AM ANT; Pin_Header_Straight_1x02
P3: PROG; Pin_Header_Straight_1x03
P4: USB_B; USB20_B_F_molex_tht_kink
R1, R4: 5R6; R_1206_HandSoldering
R2, R3, R5, R6: 2k2; R_1206_HandSoldering
R7, R8, R9: 4k7; R_1206_HandSoldering
SW1: UP; button-TACT
SW2: DOWN; button-TACT
Y1: 8MHz; Crystal_HC49-SD_SMD

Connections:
/DCLK: MCU1.25 (RB14), MCU1.26 (RB15), R3.2, R6.2
/DFS: MCU1.4 (RB0), MCU1.7 (RB3), P3.2, R2.2, R5.2
/DOUT_A: MCU1.14 (RB5), R1.2
/DOUT_B: MCU1.12 (RA4), R4.2
/RST: IC1.15 (RSTB), IC2.15 (RSTB), MCU1.6 (RB2)
/SCLK: IC1.17 (SCLK), IC2.17 (SCLK), MCU1.17 (RB8), R9.2
/SDA: IC1.18 (SDIO), IC2.18 (SDIO), MCU1.18 (RB9), R8.2
GND: C1.1, C7.2, C9.2, C10.2, C11.2, C12.2, C13.2, C14.2, C15.2, C16.2, C17.2, IC1.9 (RFGND), IC1.10 (NC), IC1.11 (NC), IC1.13 (GND), IC1.14 (GND), IC1.16 (SENB), IC2.9 (RFGND), IC2.10 (NC), IC2.11 (NC), IC2.13 (GND), IC2.14 (GND), IC3.2 (GND), IC3.3 (GND), IC3.5 (INHIBIT), IC3.6 (GND), IC3.7 (GND), MCU1.8 (VSS), MCU1.19 (Vss), MCU1.27 (AVSS), P2.1, P4.4 (GND), P4.5 (shield), SW1.2, SW2.2
unnamed: C1.2, P1.1
unnamed: C2.1, C4.1, P1.2
unnamed: C2.2, IC1.8 (FMI)
unnamed: C3.1, C5.1, P2.2
unnamed: C3.2, IC1.12 (AMI)
unnamed: C4.2, IC2.8 (FMI)
unnamed: C5.2, IC2.12 (AMI)
unnamed: C6.1, IC1.22 (DBYP)
unnamed: C8.1, IC2.22 (DBYP)
unnamed: C10.1, MCU1.9 (RA2), Y1.1
unnamed: C11.1, MCU1.10 (RA3), Y1.2
unnamed: C13.1, L1.1, P4.1 (VCC)
unnamed: C14.1, C15.1, IC3.8 (Vin), L1.2
unnamed: C17.1, MCU1.20 (VCAP)
unnamed: IC1.1 (DOUT), R1.1
unnamed: IC1.2 (DFS), R2.1
unnamed: IC1.3 (GPO3/DCLK), R3.1
unnamed: IC2.1 (DOUT), R4.1
unnamed: IC2.2 (DFS), R5.1
unnamed: IC2.3 (GPO3/DCLK), R6.1
unnamed: MCU1.1 (MCLR), P3.3, R7.2
unnamed: MCU1.5 (RB1), P3.1
unnamed: MCU1.16 (RB7), SW2.1
unnamed: MCU1.21 (RB10), P4.3 (D+)
unnamed: MCU1.22 (RB11), P4.2 (D-)
unnamed: MCU1.24 (RB13), SW1.1
VDD: C6.2, C7.1, C8.2, C9.1, C12.1, C16.1, IC1.20 (VD), IC1.21 (VA), IC2.16 (SENB), IC2.20 (VD), IC2.21 (VA), IC3.1 (VOUT), MCU1.13 (VDD), MCU1.15 (VBUS), MCU1.23 (VUSB3v3), MCU1.28 (AVDD), R7.1, R8.1, R9.1

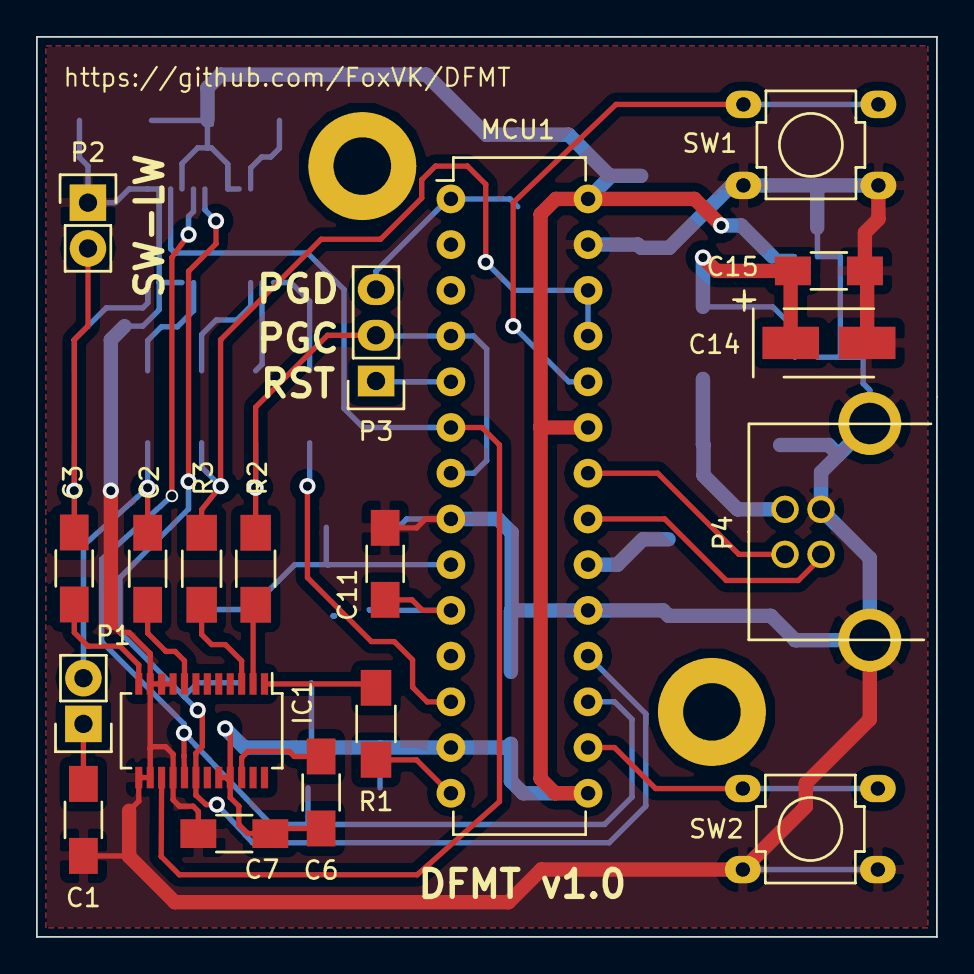
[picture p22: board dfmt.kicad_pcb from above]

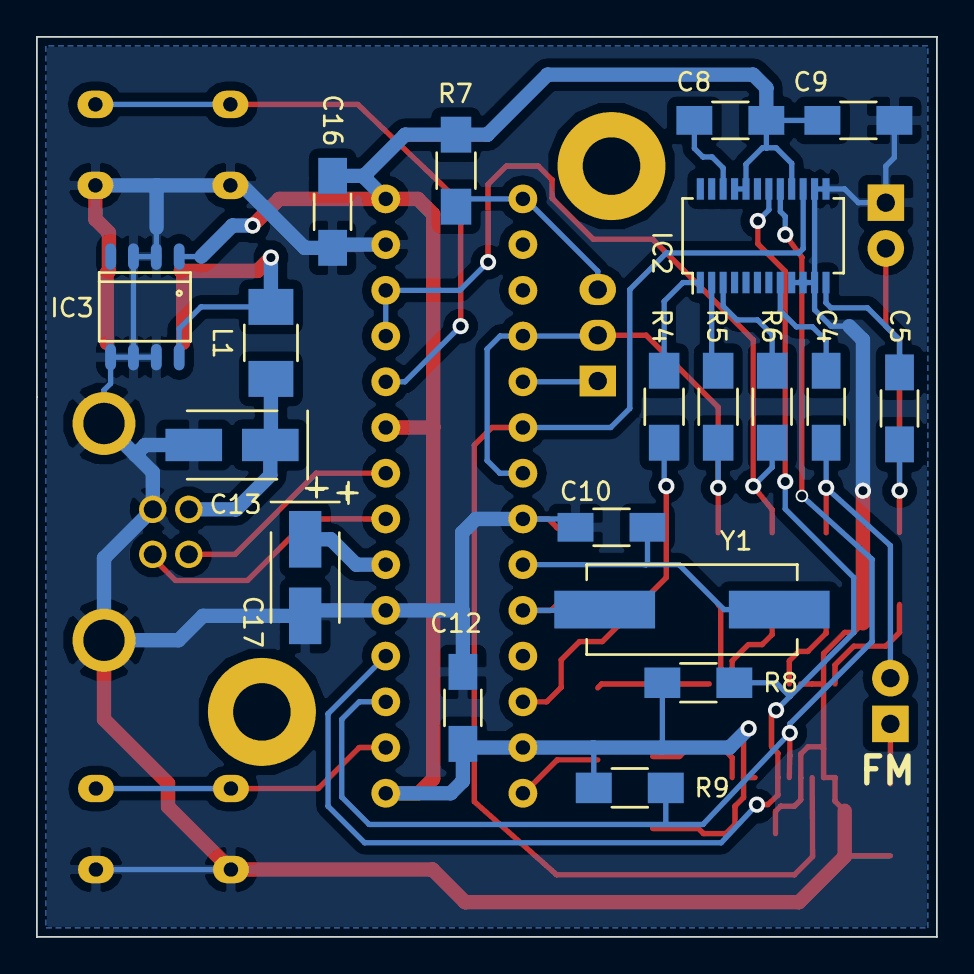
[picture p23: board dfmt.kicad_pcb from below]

Board: 2 copper layers, 50.0 x 50.0 mm, 38 parts (19 on the bottom side), 35 nets.

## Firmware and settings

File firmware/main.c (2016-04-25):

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
    Copyright: Pavel Kovar 2015 <pavel.kovar@vsetin.org>.
 */
// </editor-fold>

#include <xc.h>
#include "app_config.h"
#include "app.h"
#include "drv/debug_uart.h"
#include "drv/utils.h"



void main(void)
{
    app_config();

    //start delay
    int i,j;
    for(i=0; i<100000;i++)
        for(j=0; j<80;j++)
            _nop();

    app_init();

    while (1)
    {
        app_task();
    }
}














void _general_exception_handler (unsigned cause, unsigned status)
{
    static unsigned int _excep_addr = 0;
    asm volatile("mfc0 %0,$14" : "=r" (_excep_addr));

    char str[]="exception @ addr xxxxxx";
    uint2hex( _excep_addr, str+17, 6);
    str[23]=0;
    debug_uart_write(str);

    debughalt();
    
    switch((cause & 0x7c)>>2)
    {
        case 0 : debug_uart_write("interrupt"); break;
        case 4 : debug_uart_write("address error exception (load or ifetch)"); break;
        case 5 : debug_uart_write("address error exception (store)"); break;
        case 6 : debug_uart_write("bus error (ifetch)"); break;
        case 7 : debug_uart_write("bus error (load/store)"); break;
        case 8 : debug_uart_write("syscall"); break;
        case 9 : debug_uart_write("breakpoint"); break;
        case 10: debug_uart_write("reserved instruction"); break;
        case 11: debug_uart_write("coprocessor unusable"); break;
        case 12: debug_uart_write("arithmetic overflow"); break;
        case 13: debug_uart_write("trap (possible divide by zero)"); break;
        case 16: debug_uart_write("implementation specfic 1"); break;
        case 17: debug_uart_write("CorExtend Unuseable"); break;
        case 18: debug_uart_write("coprocessor 2"); break;
        default: debug_uart_write("Unknown reason"); break;
    }

    _nop();
    while(true)
        debug_uart_task();
}

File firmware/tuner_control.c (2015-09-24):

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
    Copyright: Pavel Kovar 2015 <pavel.kovar@vsetin.org>.
 */
// </editor-fold>

#include "tuner_control.h"
#include "inttypes.h"

#include "tuner_com.h"
#include "drv/debug_uart.h"

static bool tuner_on    = false;
static int tuners_are_on = 0; 

void tuner_control_init()
{
    
}

void tuner_control_pwr(bool state) 
{
    tuner_on = state;
}

bool tuner_control_tun_ready()
{
    return (tuners_are_on == 3) ? true : false ;
}

void tuner_control_task()
{
    /*static int i=0;
    
    if(i<100)
    {
        i++;
        tuner_hold_in_rst(1);
    }
    else
        tuner_hold_in_rst(0); //FIXME*/
    //TODO check it
    
    static uint8_t cmd_power_up[]   = {0x01, 0x00, 0xB5};
    static uint8_t cmd_power_down[] = {0x11};
    static uint8_t cmd_tune[]       = {0x20,0x01,0x24,0x9A,0x00}; //0x01 = inaccurate but fast tunning alowed to 93.7
    static uint8_t cmd_int_update[] = {0x14};
    static uint8_t cmd_int_clear[]  = {0x22, 0x01};
    static uint8_t cmd_dosr[]       = {0x12, 0x00, 0x01, 0x04, 0xBB, 0x80}; //sample rate
    static uint8_t cmd_refclk_presc[]= {0x12, 0x00, 0x02, 0x02, 0x10, 0x2F}; //1538461,538461538 / 47 -> 32733,2Hz bit 12 = 1 (colck from dclk) 0x102f
    static uint8_t cmd_refclk_freq[]= {0x12, 0x00, 0x02, 0x01, 0x7F, 0xDD}; //32733 0x7fdd

    static uint8_t * cmd_list[] = {
        NULL,
        cmd_power_up,
        cmd_refclk_freq, cmd_refclk_presc,
        cmd_tune, cmd_int_update, cmd_int_clear,
        cmd_dosr,
        NULL
    };

    static size_t cmd_sizes[] =
    {
        0,
        sizeof(cmd_power_up),
        sizeof(cmd_refclk_freq) ,sizeof(cmd_refclk_presc),
        sizeof(cmd_tune), sizeof(cmd_int_update), sizeof(cmd_int_clear),
        sizeof(cmd_dosr),
        0,

    };

    static enum {
        ST_DOWN = 0,
        ST_PWRUP,
        ST_RCLK_FREQ, ST_RCLK_PRESC,
        ST_TUNE, ST_TUNE_INT_UPDATE, ST_TUNE_INT_CLR,
        ST_DOSR,
        ST_UP,
    } state[] = {ST_DOWN, ST_DOWN};

    static enum {
        CST_DONE, CST_CHCK_REPLY, CST_READING
    } com_st[2] = {CST_DONE, CST_DONE};

    static Tuner_read_reply reply[2];
    static int tid = 1;     //ID of currently porcessed tunner

    static char *state_str[]={
        "ST_DOWN\r\n",
        "ST_PWRUP\r\n", 
        "ST_RCLK_FREQ\r\n", "ST_RCLK_PRESC\r\n",
        "ST_TUNE\r\n", "ST_TUNE_INT_UPDATE\r\n", "ST_TUNE_INT_CLR\r\n",
        "ST_DOSR\r\n",
        "ST_UP\r\n", 
    };
    
    static int last_st[] = {ST_UP, ST_UP};
    
    if(last_st[tid]!=state[tid])    
    {
        last_st[tid]=state[tid];
        static char *tun_str[] = {"TUN_A ", "TUN_B "};
        debug_uart_write(tun_str[tid]);
        debug_uart_write(state_str[state[tid]]);
    }
    
    
    {

        Tuner_com_state tun_s = tuner_com_state();

        if( tun_s == TUNER_COM_BUSY)
            return;
        
        if( tun_s == TUNER_COM_WRONG_ADDR)
        {
            char *s = "wrong addr\r\n";
            debug_uart_write(s);
        }

        tid = (tid+1)&1;

        Nop();

        switch(com_st[tid])
        {
            case CST_DONE:
                break;

            case CST_CHCK_REPLY:
                tuner_read(tid, &reply[tid], 1);
                com_st[tid] = CST_READING;
                return;

            case CST_READING:
                if(reply[tid].STATUS.bits.CTS)
                    com_st[tid] = CST_DONE;
                else
                {
                    com_st[tid] = CST_CHCK_REPLY;
                }
                return;
        }

        switch(state[tid])
        {
            case ST_UP:
                if(!tuner_on)
                {
                    tuner_hold_in_rst(1);
                    //tuner_audio_run(tid, 0);
                    state[tid] = ST_DOWN;
                }
                break;

            case ST_DOWN:
                if(tuner_on)
                {
                    //tuner_audio_run(tid, 1);
                    tuner_hold_in_rst(0);
                    state[tid]++;
                }
                break;

            case ST_TUNE_INT_CLR:
                if(!reply[tid].STATUS.bits.STCINT)
                {
                    state[tid] = ST_TUNE_INT_UPDATE;
                    break;
                }
                //do not put break here or another state

            default:
                tuner_write(tid, cmd_list[state[tid]], cmd_sizes[state[tid]]);
                com_st[tid] = CST_CHCK_REPLY;
                state[tid]++;
                break;
        }
        if(state[tid] != ST_UP)
            tuners_are_on &= ~(1 << tid);
        else
            tuners_are_on |=  (1 << tid);
    }
}

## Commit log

2015-05-14 Added uart debug funtion without iterrupts and basic device configuration.
2015-05-14 Added delay after reset.
    [main.c]
2015-05-14 Added some files for USB driver
2015-05-21 Added verz simple audio driver - working weird
2015-05-23 created eagle porject with schematic an library without MCU
    [dfmt.sch]
2015-05-23 Schematic of MCU was too big
2015-05-23 working version
    [dfmt.sch]
2015-06-03 added kicad schematic without buttons
    [dfmt.sch]
2015-06-11 finished schematic with DIP mcu and not common DFS and DCLK
    [dfmt.kicad_pcb, dfmt.sch]
2015-06-19 Added some exported files of unfinidhed board
2015-06-19 PCB second try. Unfinished
    [dfmt.kicad_pcb, dfmt.sch]
2015-08-27 Sending data from I2S to USB ready to test. I2S is alwas running Data are trasfered through pairs of chained DMA chnnels
2015-09-08 Sending data from I2S to USB is amlost working. (packet loss) I2S is alwas running Data are trasfered through pairs of chained DMA chnnels
2015-09-16 Performed investigation on packet loss. Seems to be in slow DMA. Will be sloved later
2015-09-17 Added i2c over usb tunnel but not tested
2015-09-20 First sucessful test of libdfmt Can only detect device connection and handle openeing and closing
2015-09-21 i2c over usb tunnel seems to be working fixed returning request buffers
    [tunnel.c]
2015-09-21 Tuners are not responding to i2c
2015-09-23 Added TRIS bits config for I2C
2015-09-24 Before presentation. I2C com and initialization is working. (Malfunction caused by logic analyzer) I2C over USB is probably working on MCU side Libdfmt has problem with sending of datas. Is successfu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
    [app.c]
2015-09-25 Fixed audio packet loss. Missing constants in queue inicialization...
    [tuner_audio.c]
2015-09-25 Fixed tunnel Added data01 strobing
    [app.c, tunnel.c]
2015-10-10 Borad v 1.0 without logo. Verification of USB connector needed ! There are no holes but place on edges.
    [dfmt.kicad_pcb]
2015-10-10 Images of board v1.0
2015-10-10 MiniB connector changed to mature B, but is not in the middle of board. Still no logo, no holes.
    [dfmt.sch]
2015-10-11 Added two holes.
    [dfmt.kicad_pcb]
2015-10-14 HW v1.0 sent to fab. USB connector was modified to not go outside of PCB. Actual pictures was made. Updated schematic pdf wit new USB con. Added gerber and excelon files.
    [dfmt-B_Cu.gbl, dfmt-B_Mask.gbs, dfmt-B_SilkS.gbo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]
2015-10-24 Added basic dimesions on PCB
    [dfmt.kicad_pcb]
2015-11-19 Corrected values of some components.
    [dfmt.sch]
2015-11-22 Working version of GUI with tabs, window icon and creepy menu bar. Works: seek, tunning, connecting/disconnecting tuners Mutiple tuners should by working too but not tested Not implemented: Sound. Bu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
2015-12-08 Photos of board and current screenshot of GUI
2016-01-09 Block schematic of design.
2016-01-09 Block schematic of design - added AM
2016-01-16 Added device descriptor, VID price with bib reference
2016-04-12 added Tuner intro and i2s module in mcu was joined with usb i2c tunel section
2016-04-13 Corrections and added schematic.
2016-04-24 Hope final firmaware 1.0
    Tunerd on basic optimization
    Added workaround of memroy leak to usb i2c tunel
    Added production hex dist/default/production/firmware.production.hex
    [app.c, main.c, tuner_audio.c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]
2016-04-25 Added driver instatlation
2016-04-25 Linux driver
2016-04-27 driver moved in to software
2016-04-27 Added BOM and CD structure description
2016-04-28 Added repairing driver to diploma and deleted test.c from libdfmt
2016-04-28 Diploma done B-)
    - Corrected added generated doc to libdfmt
    - Removed debug prints from gui
    - Added signed scans of some pages in diploma

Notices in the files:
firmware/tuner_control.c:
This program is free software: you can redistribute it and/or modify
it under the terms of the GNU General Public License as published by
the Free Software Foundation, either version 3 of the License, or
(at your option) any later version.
